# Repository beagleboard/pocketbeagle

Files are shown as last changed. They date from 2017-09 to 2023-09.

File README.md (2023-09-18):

# BeagleBoard.org PocketBeagle
_An even more bare-bones-BeagleBone made super-tiny, affordable and cloneable_

[PocketBeagle](https://beagleboard.org/pocket) is an ultra-tiny-yet-complete open-source USB-key-fob computer. PocketBeagle features an incredible low cost, slick design and simple usage, making PocketBeagle the ideal development board for beginners and professionals alike.

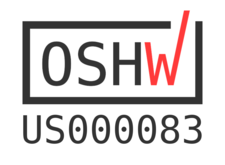
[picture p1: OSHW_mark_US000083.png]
(https://certification.oshwa.org/us000083.html)


See [documentation](https://docs.beagleboard.org/latest/boards/pocketbeagle/original/index.html) for usage details and [the forum](https://forum.beagleboard.org/tag/pocketbeagle) for support.

# Terms
These design materials are *NOT SUPPORTED* and *DO NOT* constitute a reference design. Only “community” support is allowed via resources at [BeagleBoard.org/discuss](https://beagleboard.org/discuss).

THERE IS NO WARRANTY FOR THE DESIGN MATERIALS, TO THE EXTENT PERMITTED BY APPLICABLE LAW. EXCEPT WHEN OTHERWISE STATED IN WRITING THE COPYRIGHT HOLDERS AND/OR OTHER PARTIES PROVIDE THE DESIGN MATERIALS “AS IS” WITHOUT WARRANTY OF ANY KIND, EITHER EXPRESSED OR IMPLIED, INCLUDING, BUT NOT LIMITED TO, THE IMPLIED WARRANTIES OF MERCHANTABILITY AND FITNESS FOR A PARTICULAR PURPOSE. THE ENTIRE RISK AS TO THE QUALITY AND PERFORMANCE OF THE DESIGN MATERIALS IS WITH YOU. SHOULD THE DESIGN MATERIALS PROVE DEFECTIVE, YOU ASSUME THE COST OF ALL NECESSARY SERVICING, REPAIR OR CORRECTION.

In other words, you may use the design materials as you choose and there is no license with regards to usage in the manufacturing process. We mean it, these design materials may be totally unsuitable for any purposes. Don't blame us!

As a general rule, we don't encourage use of this or other off-the-shelf single board computers in commercial products without engaging with a manufacturer to create a supplier agreement and make sure that you can get material as your business demands. Further, we do update the design on occasions where we find it necessary and won't guarantee a supply of older revisions, though we do seek periodic manufacturing of all of our boards for a period of roughly 10 years and will make design changes to replace obsolete parts and that may impact your usage. If you do opt to use it in a product, you take full responsibility for that product.

Do not use the BeagleBoard.org logo or trademarks (such as BeagleBoard, BeagleBone and PocketBeagle) on your products without a [logo license](https://beagleboard.org/logo) from the BeagleBoard.org Foundation, but feel free to reference BeagleBoard.org.

See the [LICENSE](https://github.com/beagleboard/pocketbeagle/blob/master/LICENSE) file regarding the copyright of these materials.

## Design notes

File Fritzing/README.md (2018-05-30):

# Fritzing model of PocketBeagle

[Fritzing](http://fritzing.org/) is an easy way to document your projects and even design PCBs.

This is now [upstream](https://github.com/fritzing/fritzing-parts/blob/master/core/PocketBeagle.fzp), so use the upstream version.

PocketBeagle breadboard view Breadboard style view in Fritzing

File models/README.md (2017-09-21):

This model is courtesy of Steve Smitka.

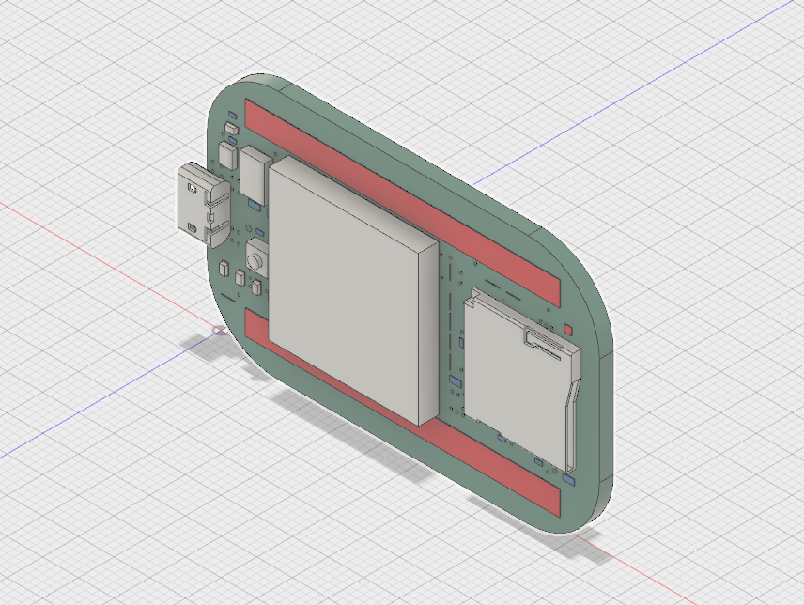
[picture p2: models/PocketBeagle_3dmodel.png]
PocketBeagle 3D model Render of 3D model


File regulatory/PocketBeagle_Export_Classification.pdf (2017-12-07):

### Commodity Classification Case Number: Z1543565 Date of Completion: December 6, 2017

UNITED STATES DEPARTMENT OF COMMERCE BUREAU OF INDUSTRY AND SECURITY WASHINGTON, D.C. 20230

FORM BXA-6002L(REV. 7/96) | Page 1 of 1

GHI Electronics
ATTN: gary beaver | G173833
501 E. Whitcomb Avenue
Madison Heights, MI 48071

THE FOLLOWING INFORMATION IS IN RESPONSE TO YOUR INQUIRY OF August 25, 2017 REQUESTING COMMODITY CLASSIFICATION(S) FOR:

COMMODITY | ECCN | SUBPARAGRAPH
PocketBeagle is an ultra-tiny-yet-complete Linux-enabled, community-supported, open-source USB-key-fob computer.
PocketBeagle
| EAR99

COMMENTS FROM LICENSING OFFICER(S):

FOR INFORMATION CONCERNING THIS CLASSIFICATION CONTACT MICHAEL PENDER
AARON AMUNDSON | PHONE #: 202-482-2458
DIVISION DIRECTOR | BIS/EA/STC/IT

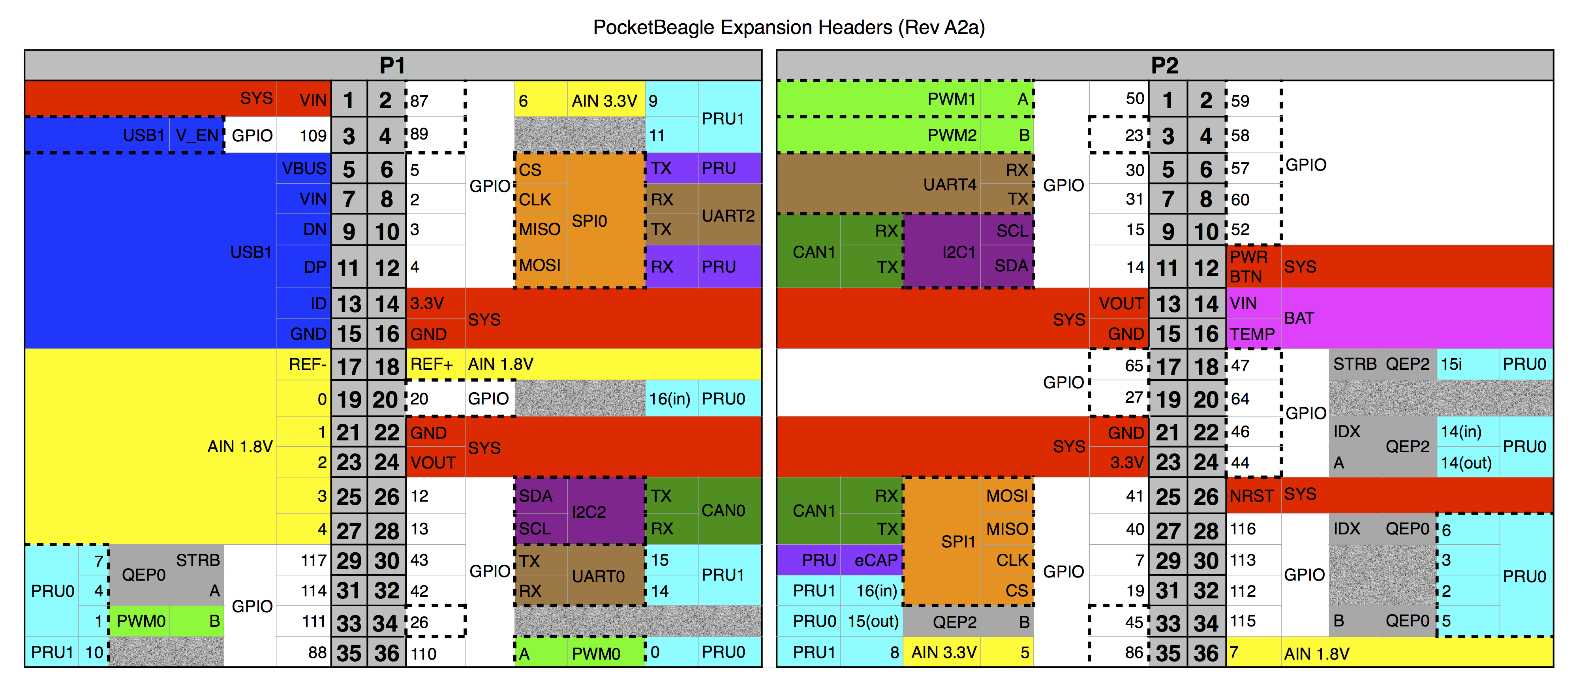
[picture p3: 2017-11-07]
docs/PocketBeagle_pinout.png

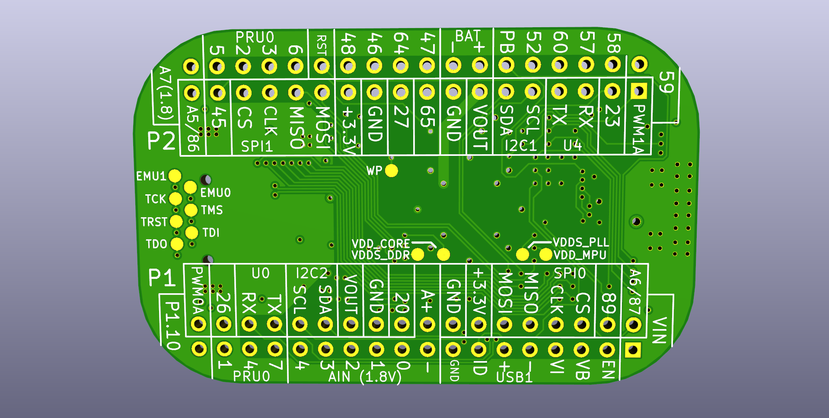
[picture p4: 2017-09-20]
KiCAD/plots/PocketBeagle-back.png

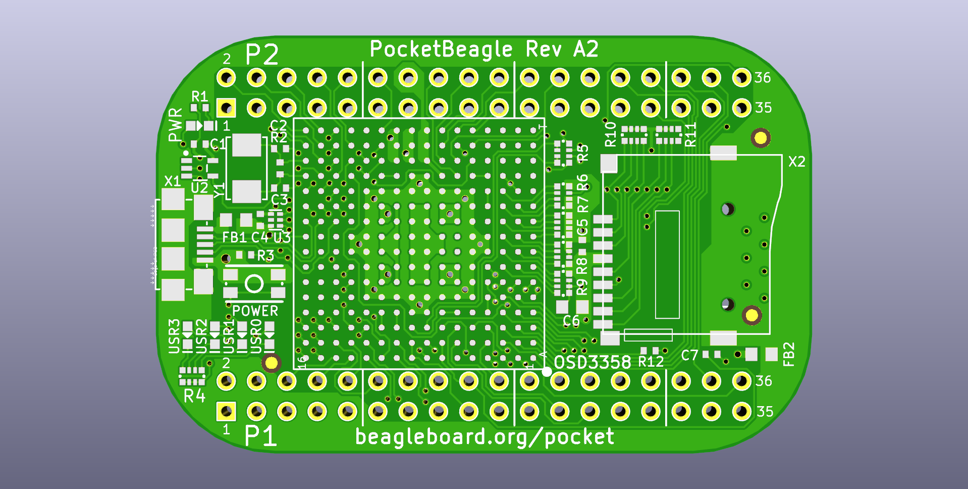
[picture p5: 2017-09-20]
KiCAD/plots/PocketBeagle-front.png

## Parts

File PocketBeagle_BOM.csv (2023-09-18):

Designator | Manufacturer/MPN | Qty | Description
 | PLACON GB1430A | 1 | 1-3/16 X1-7/8 X 1/2IN GRAPHIC BOX 770/CS
C1,C5,C7 | YAGEO CC0402KRX7R7BB104 | 3 | Cap,100nF,10%,16V,X7R,0402,YAGEO
C2,C3 | YAGEO CC0402JRNPO9BN180 | 2 | CAP 18pF 5% 50V COG 0402 SMD
C4 | YAGEO CC0402KRX5R5BB105 | 1 | CAP,1UF,+/-10%,X5R,6.3V,SMD0402
C6 | MURATA GRM21BR71A106KE51L | 1 | CAP CER 10UF 10V 10% X7R 0805 TR
D1,D2,D3,D4 | SEMITEL ESDPSA0402V05 | 4 | SMD Diode ESD 0.05pF;0402
FB1,FB2 | Laird LI0603G121R-10 | 2 | FERRITE BEAD 120 OHM 0603 1LN
POWER | C&K Components KMR231GLFS | 1 | SWITCH TACTILE SPST-NO 0.05A 32V
R1 | YAGEO RC0402FR-071KL | 1 | RES,1K,+/-1%,1/16W,SMD0402
R2 | YAGEO RC0402FR-071ML | 1 | RES,1M,+/-1%,1/16W,SMD0402
R3,R12 | YAGEO RC0402FR-0710KL | 2 | RES,10K,+/-1%,1/16W,SMD0402
R4 | YAGEO YC124-JR-071KL | 1 | RES 4 Arrays,1K,+/-5%,1/16W,SMD0804(0402X4)
R5,R10,R11 | YAGEO YC124-JR-0710KL | 3 | RES 4 Arrays,10K,+/-5%,1/16W,SMD0804(4x0402)
R6,R7,R8,R9 | YAGEO YC124-JR-07100KL | 4 | RES 4 Arrays,100K,+/-5%,1/16W,SMD0804(0402X4)
U1 | Octavo Systems OSD3358-512M-BSM | 1 | IC,the smallest System-In-Package (SiP) device in the OSD335x Family,OSD3358-512M-BSM,BGA256,SMD
U2 | Texas Instruments SN74LVC1G07DCKR | 1 | IC,SINGLE BUFFER/DRIVER WITH OPEN-DRAIN OUTPUT,SN74LVC1G07DCKR,SC-70,SMD
 | Nexperia 74LVC1G07GV,125 | 1 | IC,SINGLE BUFFER/DRIVER WITH OPEN-DRAIN OUTPUT,SN74LVC1G07DCKR,SC-70,SMD
USR0,USR1,USR2,USR3,PWR | EVERLIGHT 19-217/BHC-AN1P2/3T | 5 | LED,Blue,Water Clear,If25mA,SMD0603,464.5~476.5nm,Vf2.7~3.7v,-40~85,
X1 | MTCONN UBAF-06082, FCI 10118192-0001LF | 1 | Conn,Micro USB B,5pin,RA, SMT
X2 | MTCONN MCTF-0403, Suntech ST-TF-003A | 1 | Connector,MicroSD Card CONN with detect switch,Gold Flash 1u,Black,SMD
Y1 | Interquip 5XBB24000183TF50Q3, CTS 445A35A24M00000, TXC 7A-24.000MAAJ-T | 1 | 24MHz crystal, SMD, 5x3.2mm

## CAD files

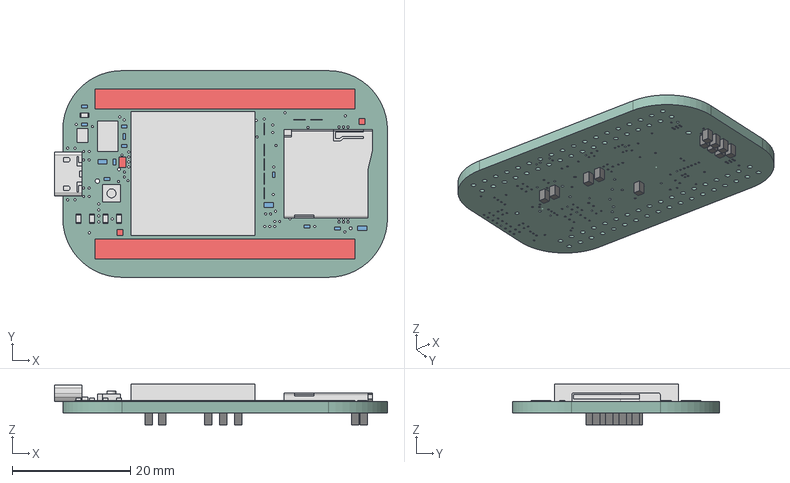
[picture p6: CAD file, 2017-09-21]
models/PocketBeagle.step
56.4 x 35.0 x 6.93 mm
Board
FIDUCIAL_40MIL x 3
0603-LED x 5
SON-6(TI)-DRY
CRYSTAL_5X3.2MM
SC70(TI-DCK)
RN0804 x 8
OSD335X-BGA-256
TH-2X18-(35MIL-DIA)-W_O-SILK x 2
B1,27 x 12
chip
sdholder
microusb port
button
leds
y1chip
powerLED
c1chip

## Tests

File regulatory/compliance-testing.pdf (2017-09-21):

Registration #
6844A-3 | Testing Laboratory

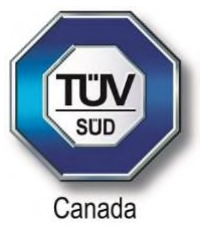
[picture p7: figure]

| Certificate #2955.02 | R-4023, G-506
| | C-4498, T-1246 Registration #
| | CA6844
Page 1 of 50 | Report Issued: 9/11/2017 | Report File #: 7169003158E-000

© TÜV SÜD Canada Inc. This test report shall not be reproduced except in full, without written approval of TÜV SÜD Canada Inc CISPR32-24_FCC_ICES_Rev2

## EMC / EMI Test Report

As per
CISPR 32:2015/EN 55032:2015, CISPR 24:2010/EN 55024:2010, AS/NZS CISPR 32:2013,

## FCC Part 15 Subpart B:2016 & ICES-003:2016

Emissions & Immunity for

Multimedia Class B Equipment on the

## Pocket Beagle A2

Issued by: | TÜV SÜD Canada Inc. 11 Gordon Collins Dr, Gormley, ON, L0H 1G0 Canada Ph: (905) 883-7255

Testing produced for

See Appendix A for full client & EUT details.
Name,
Project Engineer

Client | BeagleBoard.org Foundation
Product | PocketBeagle A2
Standard(s) | FCC Part 15 Subpart B / ICES-003 CISPR 32/EN55032 & CISPR 24/EN55024
Page 2 of 50 | Report Issued: 9/11/2017 | Report File #: 7169003158E-000

## Table of Contents

Product | PocketBeagle A2
Standard(s) | FCC Part 15 Subpart B / ICES-003 CISPR 32/EN55032 & CISPR 24/EN55024
Page 3 of 50 | Report Issued: 9/11/2017 | Report File #: 7169003158E-000

## Report Scope

This report addresses the EMC verification testing and test results of the BeagleBone, Pocket Beagle, Model: A2, herein referred to as EUT (Equipment Under Test). The EUT was tested for emissions and immunity compliance against the following standards:

EN 55032:2012/CISPR 32:2012

EN 55024:2010/CISPR 24:2010

AS/NZS CISPR 32:2013

FCC Part 15 Subpart B:2016

ICES-003:2016

Power line conducted emissions, radiated emissions, harmonics emissions, flicker emissions, and immunity testing was evaluated on the EUT. Test procedures, results, justifications, and engineering considerations, if any, follow later in this report.

For a more detailed list of the standards and the revision used, see the "Applicable Standards, Specifications and Methods" section of this report.

This report does not imply product endorsement by any government, accreditation agency, or TÜV SÜD Canada Inc.

Opinions or interpretations expressed in this report, if any, are outside the scope of TÜV SÜD Canada Inc. accreditations. Any opinions expressed do not necessarily reflect the opinions of TÜV SÜD Canada Inc., unless otherwise stated.

Product | PocketBeagle A2
Standard(s) | FCC Part 15 Subpart B / ICES-003 CISPR 32/EN55032 & CISPR 24/EN55024
Page 4 of 50 | Report Issued: 9/11/2017 | Report File #: 7169003158E-000

## Summary

The results contained in this report relate only to the item(s) tested.

Equipment Under Test (EUT) | Pocket Beagle
EUT passed all tests performed | Yes
Testing conducted by | Marty McLear

For testing dates, see 'Testing Environmental Conditions and Dates'.

Product | PocketBeagle A2
Standard(s) | FCC Part 15 Subpart B / ICES-003 CISPR 32/EN55032 & CISPR 24/EN55024
Page 5 of 50 | Report Issued: 9/11/2017 | Report File #: 7169003158E-000

Test Results Summary

Standard/ Method | Description | Criteria | Class / Level | Result
EN 55032/ CISPR 32 FCC 15 - ICES 003 | Radiated Emissions | N/A | Class B | Pass
EN 55024/ EN 61000-4-2 | Electro-Static Discharge | B | ±4kV Contact ±8kV Air | Pass
EN 55024/ EN 61000-4-3 | Radiated Field Immunity | A | 3 V/m, 80 MHz – 1 GHz | Pass
EN 55024/ EN 61000-4-4 | Electrical Fast Transients (Bursts) | B | ±0.5kV - I/O | Pass
EN 55024/ EN 61000-4-8 | Power Frequency Magnetic Field | A | 1 A/m (3 A/m Tested) | Pass
Overall Result | | | | Pass

If the product as tested complies with the specification or requirement, the EUT is deemed to comply and is issued a 'PASS' grade. If not, 'FAIL' grade is issued.

Product | PocketBeagle A2
Standard(s) | FCC Part 15 Subpart B / ICES-003 CISPR 32/EN55032 & CISPR 24/EN55024
Page 6 of 50 | Report Issued: 9/11/2017 | Report File #: 7169003158E-000

Notes, Justifications, or Deviations
The following justifications for tests not performed or deviations from the above listed specifications apply:

Client has stated that this equipment is consider a DC device and that the EUT is not intended to be used with a AC/DC power adaptor as part of their system.
The following tests are therefore not applicable for a DC powered device:
- Conducted Emissions
- Power Line Harmonics Emissions
- Flicker Emissions
- Surge Immunity
- Conducted RF Immunity
- Voltage Dips and Interrupts

The client has indicated that the EUT / PCB will be ESD Sensitive and is marked with the ESD Sensitive marking on the silk screen of the PCB.

A later revision of the standard may have been substituted in place of the previous dated referenced revision. The year of the specification used is listed under applicable standards. Using the later revision accomplishes the goal of ensuring compliance to the intent of the previous specification, while allowing the laboratory to incorporate the extensions and clarifications made available by a later revision.

Sample Calculation(s)
Radiated Emission Test
Margin = Limit – (Received Signal + Antenna Factor + Cable Loss – Pre-Amp Gain) Margin = 50dBµV/m – (50dBµV + 10dB + 2.5dB – 20dB)
Margin = 7.5 dB (pass)

Power Line Conducted Emission Test
Margin = Limit – (Received Signal + Attenuation Factor + Cable Loss + LISN Factor) Margin = 73.0dBµV – (50dBµV + 10dB + 2.5dB + 0.5dB)
Margin = 10.0 dB (pass)

Milligauss to A/m Conversion (Magnetic Immunity)
1A/m = 12.57 mG
3A/m = 3*12.57 = 37.7 mG

Product | PocketBeagle A2
Standard(s) | FCC Part 15 Subpart B / ICES-003 CISPR 32/EN55032 & CISPR 24/EN55024
Page 7 of 50 | Report Issued: 9/11/2017 | Report File #: 7169003158E-000

## Applicable Standards, Specifications and Methods

ANSI C63.4:2014 Methods of Measurement of Radio-Noise Emissions from Low-Voltage Electrical and Electronic Equipment in the Range of 9 kHz to 40 GHz CFR47 FCC Part 15
Subpart B:2016

Code of Federal Regulations - Radio Frequency Devices

ICES-003, Issue 6
2016

Information Technology Equipment (ITE) - Limits and Methods of Measurement
EN55032:2012/
CISPR32:2012

Electromagnetic Compatibility of Multimedia Equipment – Emission Requirements
EN55024:2010/
CISPR24:2010

Information Technology Equipment - Immunity Characteristics -Limits and Methods of Measurement
AS/NZS CISPR32:2013 Electromagnetic Compatibility of Multimedia Equipment – Emission Requirements
CISPR 16-2-3:2010/A2:2014 Specification for Radio Disturbance and Immunity Measuring Apparatus and Methods - Part 2-3: Methods of Measurement of Disturbances and Immunity - Radiated Disturbance Measurements
IEC/EN 61000-3-2:2014 Limits for Harmonic Current Emissions
(equipment input current ≤ 16A per phase)
IEC/EN 61000-3-3:2013 Limitation of Voltage Changes, Voltage Fluctuations and Flicker in Public Low-Voltage Supply Systems, for equipment with rated current ≤ 16A per phase and not subject to conditional connection. IEC 61000-4-2:2008
EN 61000-4-2:2009

Testing and Measurement Techniques -
Electrostatic Discharge Immunity Test IEC/EN 61000-4-3:2006/
A2:2010

Testing and Measurement Techniques -
Radiated, Radio-Frequency, Electromagnetic Field Immunity Test IEC/EN 61000-4-4:2004 Testing and Measurement Techniques -Electrical Fast Transient/Burst Immunity Test
IEC 61000-4-5:2005
EN 61000-4-5:2006

Testing and Measurement Techniques - Surge Immunity Test

IEC 61000-4-6:2008
EN 61000-4-6:2009

Testing and Measurement Techniques - Immunity to Conducted Disturbances, Induced by Radio-Frequency Fields
IEC 61000-4-8:2009
EN 61000-4-8:2010

Testing and Measurement Techniques -
Power Frequency Magnetic Field Immunity Test IEC/EN 61000-4-11:2004 Testing and Measurement Techniques - Voltage Dips, Short Interruptions and Voltage Variations Immunity Tests
ISO 17025:2005 General Requirements for the Competence of Testing and Calibration Laboratories

Product | PocketBeagle A2
Standard(s) | FCC Part 15 Subpart B / ICES-003 CISPR 32/EN55032 & CISPR 24/EN55024
Page 8 of 50 | Report Issued: 9/11/2017 | Report File #: 7169003158E-000

## Document Revision Status

Revision 0 September 8th, 2017 Initial Release

Product | PocketBeagle A2
Standard(s) | FCC Part 15 Subpart B / ICES-003 CISPR 32/EN55032 & CISPR 24/EN55024
Page 9 of 50 | Report Issued: 9/11/2017 | Report File #: 7169003158E-000

## Definitions and Acronyms

The following definitions and acronyms are applicable in this report. See also ANSI C63.14.

AM – Amplitude Modulation
CDN – Coupling Decoupling Network
EFT – Electrical Fast Transients
ESD – Electro-Static Discharge
HCP – Horizontal Coupling Plane
VCP – Vertical Coupling Plane
LISN – Line Impedance Stabilization Network NCR – No Calibration Required
NSA – Normalized Site Attenuation
N/A – Not Applicable
RF – Radio Frequency

AE – Associated Equipment. Equipment needed to exercise and/or monitor the operation of the EUT.

Class A Device – A device that is marketed for use in a commercial, industrial or business environment. A 'Class A' device should not be marketed for use by the general public. A 'Class A' device should contain a warning notice in the user manual stating that it could cause radio interference. For example: "Warning: Operation of this equipment in a residential environment could cause radio interference."

Class B Device – A device that is marketed for use in a residential environment and may also be used in a commercial, business or industrial environments. NOTE: A residential environment is an environment where the use of broadcast radio and television receivers may be expected within a distance of 10m of the device concerned.

EMC – Electro-Magnetic Compatibility. The ability of an equipment or system to function satisfactorily in its electromagnetic environment without introducing intolerable electromagnetic disturbances to anything in that environment.

EMI – Electro-Magnetic Immunity. The ability to maintain a specified performance when the equipment is subjected to disturbance (unwanted) signals of specified levels.

EUT – Equipment Under Test. A device or system being evaluated for compliance that is representative of a product to be marketed.

Product | PocketBeagle A2
Standard(s) | FCC Part 15 Subpart B / ICES-003 CISPR 32/EN55032 & CISPR 24/EN55024
Page 10 of 50 | Report Issued: 9/11/2017 | Report File #: 7169003158E-000

ITE – Information Technology Equipment. Has a primary function of entry, storage, display, retrieval, transmission, processing, switching, or control of data and/or telecommunication messages and which may be equipped with one or more ports typically for information transfer.

Antenna Port – Port, other than a broadcast receiver tuner port, for connection of an antenna used for intentional transmission and/or reception of radiated RF energy.

Broadcast Receiver Tuner Port – Port intended for the reception of a modulated RF signal carrying terrestrial, satellite and/or cable transmissions of audio and/or video broadcast and similar services.

Optical Fiber Port – Port at which an optical fiber is connected to an equipment.

Signal/Control Port – Port intended for the interconnection of components of a EUT, or between a EUT and local AE and used in accordance with relevant functional specifications (for example for the maximum length of cable connected to it).
(Examples include: RS-232, USB, HDMI, Fire Wire)

Wired Network Port – Point of connection for voice, data and signaling transfers intended to interconnect widely dispersed systems by direct connection to a single-user or multi-user communication network.
(Examples include: CATV, PSTN, ISDN, xDSL, LAN and similar networks)

EMC Test Plan – An EMC test plan established prior to testing. See 'Appendix A – EUT & Client Provided Details'.

Product | PocketBeagle A2
Standard(s) | FCC Part 15 Subpart B / ICES-003 CISPR 32/EN55032 & CISPR 24/EN55024
Page 11 of 50 | Report Issued: 9/11/2017 | Report File #: 7169003158E-000

## Testing Facility

Testing for EMC on the EUT was carried out at TÜV SÜD Canada testing lab near Toronto, Ontario. The testing lab has a calibrated 3m semi-anechoic chamber which allows measurements on a EUT that has a maximum width or length of up to 2m and a height of up to 3m. The chamber is equipped with a turntable that is capable of testing devices up to 3300lb in weight. This facility is capable of testing products that are rated for 120Vac and 240Vac single phase, or devices that are rated for a 208Vac 3 phase input. DC capability is also available for testing. The chamber is equipped with a mast that controls the polarization and height of the antenna. Control of the mast occurs in the control room adjoining the shielded chamber. Radiated emission measurements are performed using a BiLog antenna and a Horn antenna where applicable. Conducted emissions, unless otherwise stated, are performed using a LISN and using the Vertical Ground plane if applicable.

Calibrations and Accreditations
The 3m semi-anechoic chamber is registered with Federal Communications Commission (FCC, CA6844), Industry Canada (IC, 6844A-3) and Voluntary Control Council for Interference (VCCI, R-4023, G-506, C-4498, and T-1246). This chamber was calibrated for Normalized Site Attenuation (NSA) using test procedures outlined in ANSI C63.4 "Methods of Measurement of Radio-Noise Emissions from Low-Voltage Electrical and Electronic Equipment in the Range of 9 kHz to 40 GHz". The chamber is lined with ferrite tiles and absorption cones to minimize any undesired reflections. The NSA data is kept on file at TÜV SÜD Canada. For radiated susceptibility testing, a 16 point field calibration has been performed on the chamber. The field uniformity data is kept on file at TÜV SÜD Canada. TÜV SÜD Canada Inc. is accredited to ISO 17025 by A2LA with Testing Certificate #2955.02. The laboratory's current scope of accreditation listing can be found as listed on the A2LA website. All measuring equipment is calibrated on an annual or bi-annual basis as listed for each respective test.

Product | PocketBeagle A2
Standard(s) | FCC Part 15 Subpart B / ICES-003 CISPR 32/EN55032 & CISPR 24/EN55024
Page 12 of 50 | Report Issued: 9/11/2017 | Report File #: 7169003158E-000

Testing Environmental Conditions and Dates
Following environmental conditions were recorded in the facility during time of testing:
Date | Test | Initials | Temperature (ºC) | Humidity (%) | Pressure (kPa)
September 6th, 2017 | Radiated Emissions | MM | 23.5 | 49.3 | 100.5
September 6th, 2017 | Electro-Static Discharge | MM | 23.5 | 49.3 | 100.5
September 6th, 2017 | Radiated Field Immunity | MM | 23.5 | 49.3 | 100.5
September 5th, 2017 | Electrical Fast Transients | MM | 22.1 | 56.1 | 99.9
September 6th, 2017 | Power Frequency Magnetic Field | MM | 23.5 | 49.3 | 100.5

Product | PocketBeagle A2
Standard(s) | FCC Part 15 Subpart B / ICES-003 CISPR 32/EN55032 & CISPR 24/EN55024
Page 13 of 50 | Report Issued: 9/11/2017 | Report File #: 7169003158E-000

## Detailed Test Result Section

Product | PocketBeagle A2
Standard(s) | FCC Part 15 Subpart B / ICES-003 CISPR 32/EN55032 & CISPR 24/EN55024
Page 14 of 50 | Report Issued: 9/11/2017 | Report File #: 7169003158E-000

Radiated Emissions

Purpose
The purpose of this test is to ensure that the RF energy unintentionally emitted from the EUT does not exceed the limits listed below as defined in the applicable test standard and measured from a receiving antenna. This helps protect broadcast radio services such as television, FM radio, pagers, cellular telephones, emergency services, and so on, from unwanted interference.

Limits & Method
The limits and method are as defined in ANSI C63.4 and CISPR 32, EN55032, 47 CFR FCC Part 15 Section 15.109(g), and ICES-003 Issue 6 Section 6.2:
CLASS A
Frequency Rangea | Quasi-Peak Limits - 10mb | Quasi-Peak Limits - 3mb
30 MHz – 230 MHz | 40 dBµV/m | 50 dBµV/m
230 MHz – 1 GHz | 47 dBµV/m | 57 dBµV/m

CISPR 32 / EN 55032,
Frequency Rangea | Average Limit - 3mc | Peak Limit - 3md
1 GHz – 3 GHz | 56 dBµV/m | 76 dBµV/m
3 GHz – 6 GHz | 60 dBµV/m | 80 dBµV/m

FCC Part 15 Subpart B,
Frequency Rangea | Average Limit - 3mc | Peak Limit - 3md
1 GHz and Up | 60 dBµV/m | 80 dBµV/m

aThe frequency range scanned is in accordance to CISPR 32 Table 1 and FCC Part 15 Section 15.33(b).
bLimit is with a resolution bandwidth of 120 kHz, a video bandwidth at least three times greater than the resolution bandwidth, and using a Quasi-Peak detector.
cLimit is with a resolution bandwidth of 1 MHz and using an Average detector.
dLimit is with a resolution bandwidth of 1 MHz, a video bandwidth at least three times greater than the resolution bandwidth, and using a Peak detector.

Based on ANSI C63.4 Section 4.2 and CISPR 32 Annex C.3, if the Peak detector measurements do not exceed the Quasi-Peak limits, where defined, then the EUT is deemed to have passed the requirements.

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

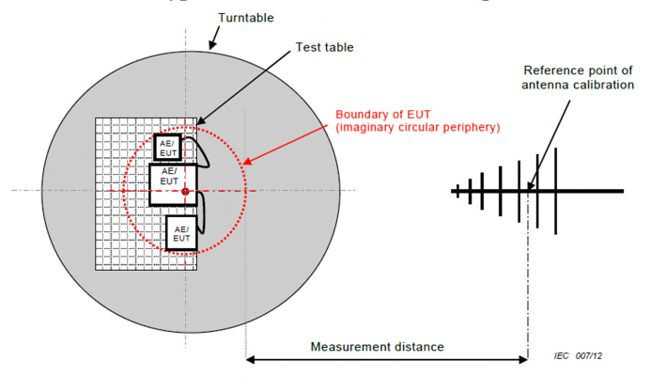
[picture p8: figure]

Page 15 of 50 | Report Issued: 9/11/2017 | Report File #: 7169003158E-000

Typical Radiated Emissions Setup

Note: In accordance with CISPR 32 Annex C, testing was performed at a 3 meter test distance.

Measurement Uncertainty
The expanded measurement uncertainty is calculated in accordance with CISPR 16-4-2 and is ±4.25dB for 30MHz – 1GHz and ±4.93dB for 1GHz – 18GHz with a 'k=2' coverage factor and a 95% confidence level.

Preliminary Graphs
The graphs shown below are maximized peak measurement graphs measured with a resolution bandwidth greater than or equal to the final required detector over a full 0-360°. This peaking process is done as a worst case measurement and enables the detection of frequencies of concern for final measurement. For final measurements with the appropriate detector, where applicable, please refer to the tables under Final Measurements.

In accordance with FCC Part 15, Subpart A, Section 15.33 and CISPR 32 Table 1, the EUT was scanned to a minimum of a 1 GHz. For devices containing clocks higher than 108 MHz, they were scanned above 1 GHz to meet the requirements of FCC Part 15 Section 15.33 and CISPR 32.

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

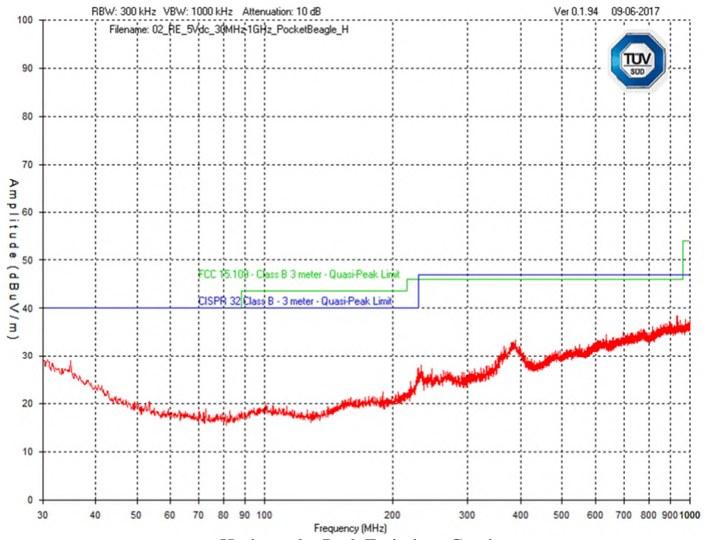
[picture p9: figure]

Page 16 of 50 | Report Issued: 9/11/2017 | Report File #: 7169003158E-000

Horizontal – Peak Emissions Graph 5Vdc – 30MHz - 1GHz

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

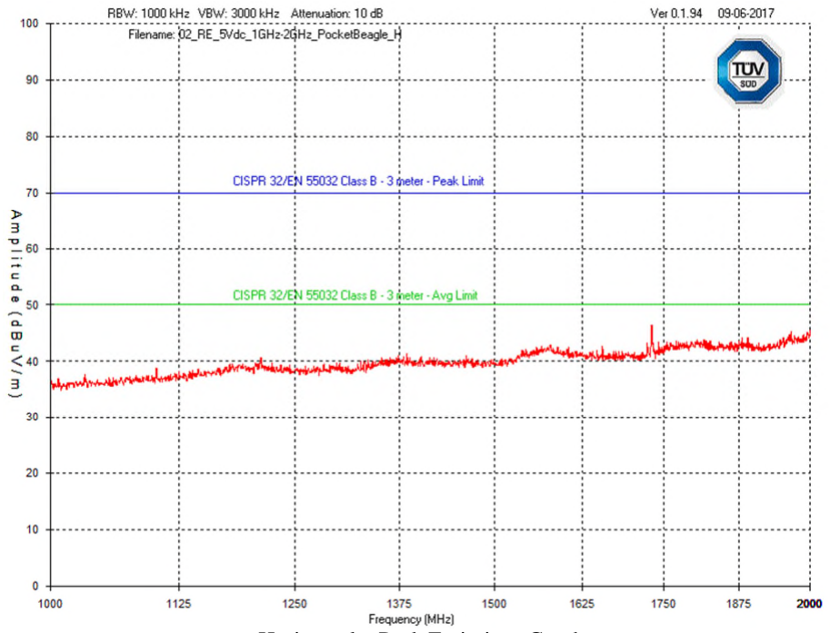
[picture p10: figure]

Page 17 of 50 | Report Issued: 9/11/2017 | Report File #: 7169003158E-000

Horizontal – Peak Emissions Graph 5Vdc – 1GHz - 2GHz (CISPR 32/EN 55032)

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

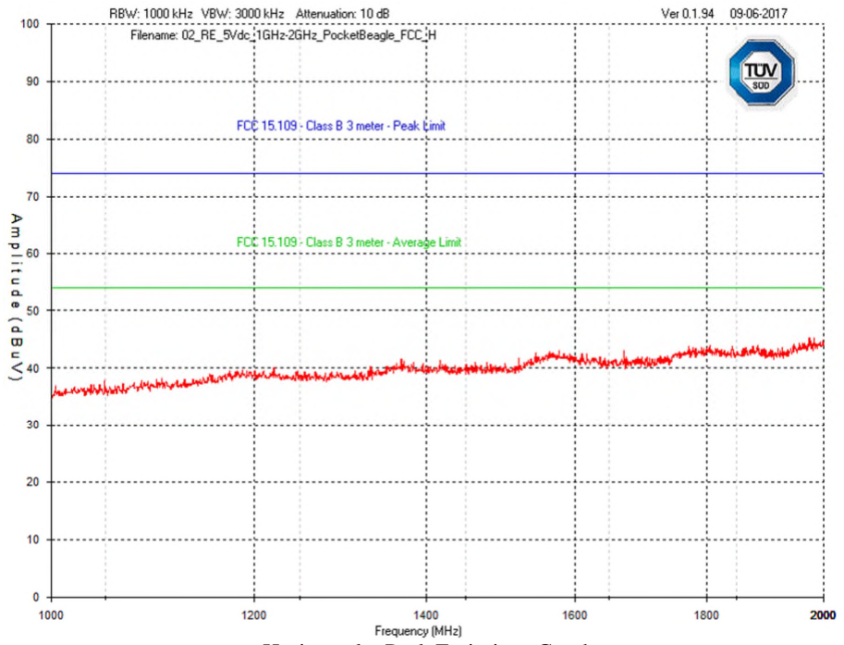
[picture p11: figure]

Page 18 of 50 | Report Issued: 9/11/2017 | Report File #: 7169003158E-000

Horizontal – Peak Emissions Graph 5Vdc – 1GHz - 2GHz (FCC 15.109)

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

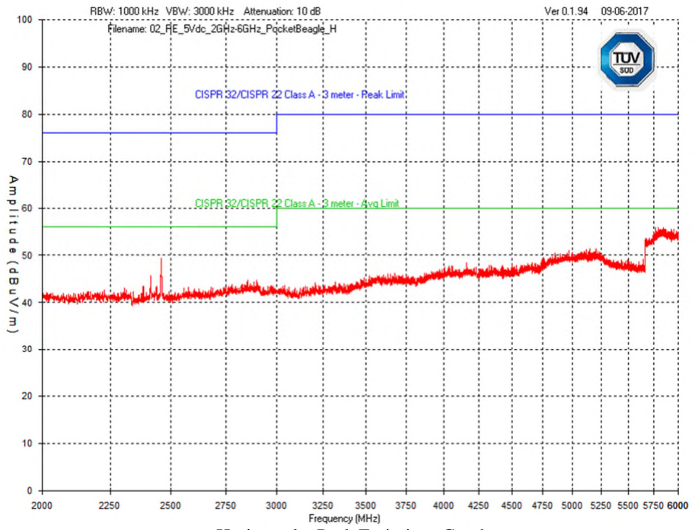
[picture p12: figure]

Page 19 of 50 | Report Issued: 9/11/2017 | Report File #: 7169003158E-000

Horizontal – Peak Emissions Graph 5Vdc – 2GHz - 6GHz (CISPR 32/EN 55032)

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

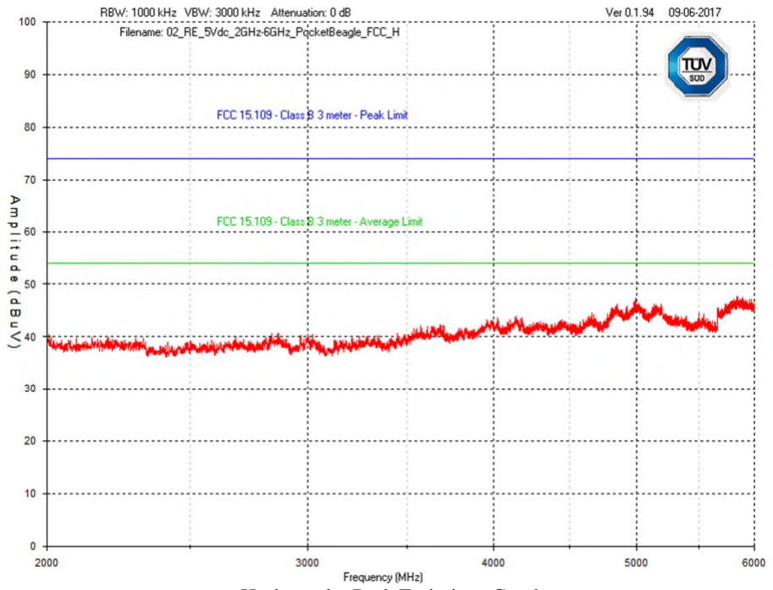
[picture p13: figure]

Page 20 of 50 | Report Issued: 9/11/2017 | Report File #: 7169003158E-000

Horizontal – Peak Emissions Graph 5Vdc – 2GHz - 6GHz (FCC 15.109)

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

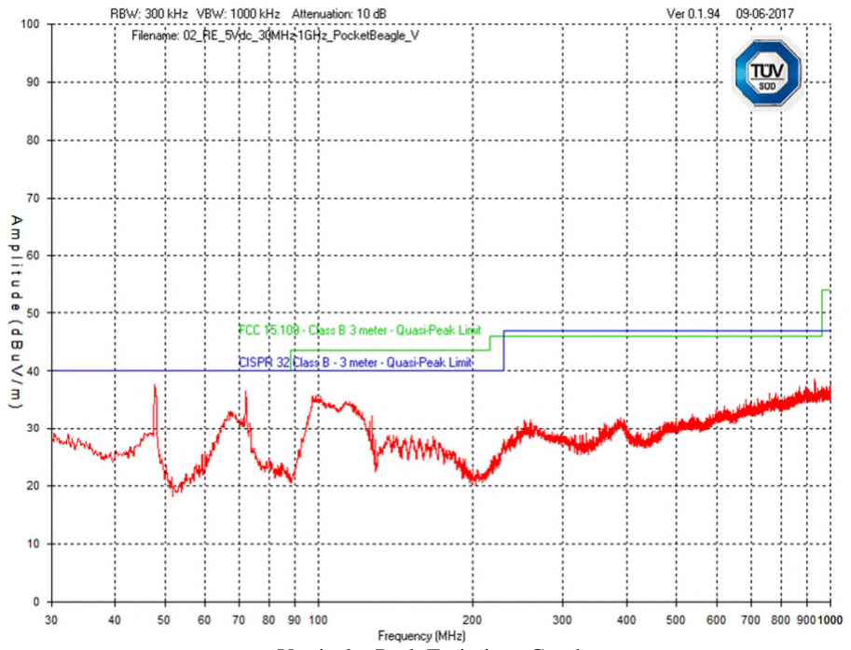
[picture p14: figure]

Page 21 of 50 | Report Issued: 9/11/2017 | Report File #: 7169003158E-000

Vertical – Peak Emissions Graph 5Vdc – 30MHz - 1GHz

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

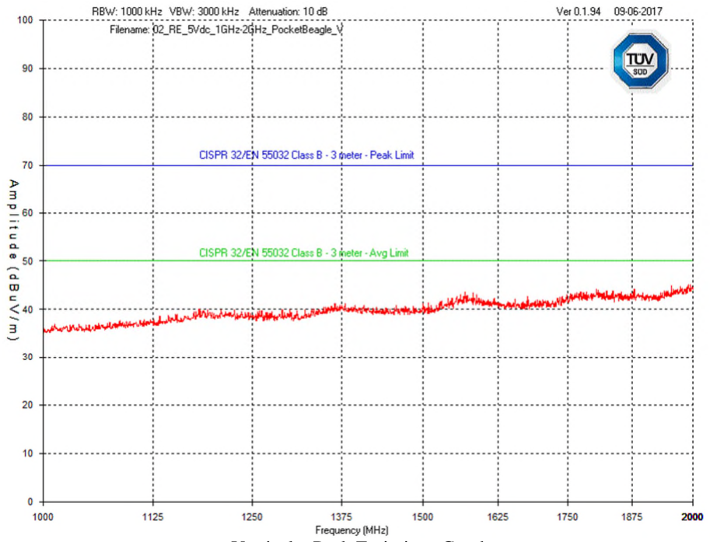
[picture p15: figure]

Page 22 of 50 | Report Issued: 9/11/2017 | Report File #: 7169003158E-000

Vertical – Peak Emissions Graph 5Vdc – 1GHz - 2GHz (CISPR 32/EN 55032)

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

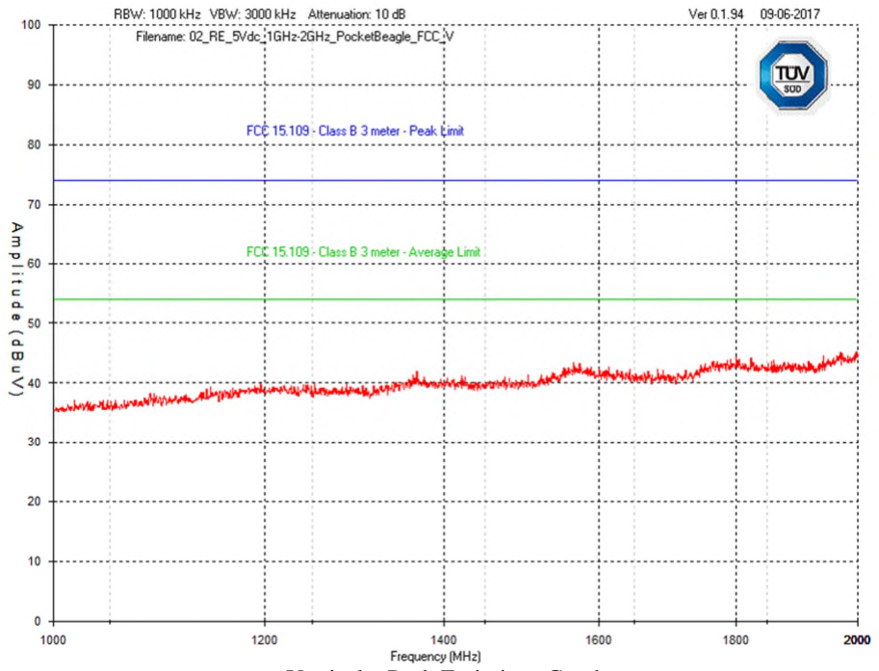
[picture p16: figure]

Page 23 of 50 | Report Issued: 9/11/2017 | Report File #: 7169003158E-000

Vertical – Peak Emissions Graph 5Vdc – 1GHz - 2GHz (FCC 15.109)

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


Page 24 of 50 | Report Issued: 9/11/2017 | Report File #: 7169003158E-000

Vertical – Peak Emissions Graph 5Vdc – 2GHz - 6GHz (CISPR 32/EN 55032)

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


Page 25 of 50 | Report Issued: 9/11/2017 | Report File #: 7169003158E-000

Vertical – Peak Emissions Graph 5Vdc – 2GHz - 6GHz (FCC 15.109)

Product | PocketBeagle A2
Standard(s) | FCC Part 15 Subpart B / ICES-003 CISPR 32/EN55032 & CISPR 24/EN55024
Page 26 of 50 | Report Issued: 9/11/2017 | Report File #: 7169003158E-000

Final Measurements
The worst case measurement as listed in the table below appeared at a vertical antenna height of 100 cm and a table azimuth of 360 degrees, as pictured in Appendix B.
Product Category | Class B - CISPR 32/ EN 55032
Supply | 5Vdc
Frequency (MHz) | Detector Peak/QP | Received Signal (dBµV) | Antenna Factor (dB/m) | Atten Factor (dB) | Cable Factor (dB) | Pre-Amp (dB) | Level (dBµV/m) | QP Limit (dBµV/m) | QP Margin (dB) | Pass/ Fail

Horizontal Antenna Polarization
45.43 | QP | 28.5 | 9.0 | 6 | 0.4 | -31.7 | 12.2 | 40.0 | 27.8 | Pass
712.00 | QP | 39.8 | 6.4 | 6 | 0.5 | -32.5 | 20.2 | 40.0 | 19.8 | Pass
47.85 | PEAK | 54.0 | 9.0 | 6 | 0.4 | -31.7 | 37.7 | 40.0 | 2.3 | Pass
71.90 | PEAK | 56.2 | 6.4 | 6 | 0.5 | -32.5 | 36.6 | 40.0 | 3.4 | Pass
98.87 | PEAK | 54.3 | 8.0 | 6 | 0.6 | -33.0 | 35.9 | 40.0 | 4.1 | Pass
992.82 | PEAK | 36.7 | 23.8 | 6 | 2.5 | -33.2 | 35.8 | 47.0 | 11.2 | Pass
Vertical Antenna Polarization
931.62 | PEAK | 39.9 | 23.4 | 6 | 2.3 | -33.2 | 38.4 | 47.0 | 8.6 | Pass
30.78 | PEAK | 36.4 | 17.3 | 6 | 0.3 | -30.9 | 29.1 | 40.0 | 10.9 | Pass
763.42 | PEAK | 37.2 | 22.3 | 6 | 2.1 | -33.4 | 34.2 | 47.0 | 12.8 | Pass
388.22 | PEAK | 43.2 | 16.5 | 6 | 1.4 | -33.6 | 33.5 | 47.0 | 13.5 | Pass
233.41 | PEAK | 42.9 | 11.7 | 6 | 1.0 | -33.6 | 28.0 | 47.0 | 19.0 | Pass
246.99 | PEAK | 41.7 | 12.2 | 6 | 1.0 | -33.6 | 27.3 | 47.0 | 19.7 | Pass

Quasi-Peak Emissions Table - CISPR 32/ EN 55032

Product | PocketBeagle A2
Standard(s) | FCC Part 15 Subpart B / ICES-003 CISPR 32/EN55032 & CISPR 24/EN55024
Page 27 of 50 | Report Issued: 9/11/2017 | Report File #: 7169003158E-000
Product Category | Class B - FCC Subpart B 15.109
Supply | 5Vdc
Frequency (MHz) | Detector Peak/QP | Received Signal (dBµV) | Antenna Factor (dB/m) | Atten Factor (dB) | Cable Factor (dB) | Pre-Amp (dB) | Level (dBµV/m) | QP Limit (dBµV/m) | QP Margin (dB) | Pass/ Fail

Horizontal Antenna Polarization
45.43 | QP | 28.5 | 9.0 | 6 | 0.4 | -31.7 | 12.2 | 40.0 | 27.8 | Pass
712.00 | QP | 39.8 | 6.4 | 6 | 0.5 | -32.5 | 20.2 | 40.0 | 19.8 | Pass
47.85 | PEAK | 54.0 | 9.0 | 6 | 0.4 | -31.7 | 37.7 | 40.0 | 2.3 | Pass
71.90 | PEAK | 56.2 | 6.4 | 6 | 0.5 | -32.5 | 36.6 | 40.0 | 3.4 | Pass
98.87 | PEAK | 54.3 | 8.0 | 6 | 0.6 | -33.0 | 35.9 | 43.5 | 7.6 | Pass
992.82 | PEAK | 36.7 | 23.8 | 6 | 2.5 | -33.2 | 35.8 | 54.0 | 18.2 | Pass
Vertical Antenna Polarization
931.62 | PEAK | 39.9 | 23.4 | 6 | 2.3 | -33.2 | 38.4 | 46.0 | 7.6 | Pass
30.78 | PEAK | 36.4 | 17.3 | 6 | 0.3 | -30.9 | 29.1 | 40.0 | 10.9 | Pass
763.42 | PEAK | 37.2 | 22.3 | 6 | 2.1 | -33.4 | 34.2 | 46.0 | 11.8 | Pass
388.22 | PEAK | 43.2 | 16.5 | 6 | 1.4 | -33.6 | 33.5 | 46.0 | 12.5 | Pass
233.41 | PEAK | 42.9 | 11.7 | 6 | 1.0 | -33.6 | 28.0 | 46.0 | 18.0 | Pass
246.99 | PEAK | 41.7 | 12.2 | 6 | 1.0 | -33.6 | 27.3 | 46.0 | 18.7 | Pass

Quasi-Peak Emissions Table – FCC Subpart B 15.109

Note:
Peak = Peak measurement
QP = Quasi-Peak measurement
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

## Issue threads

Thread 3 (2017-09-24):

Boot debugging

yuvadm, 2017-09-24:
I'm attempting to boot an existing BeagleBone image I have on an SD card (and then debug to see if there are any require changes for the new board), however I'm not getting any signs of life from the board other than a steady blue LED.

Are there any hardware pins I can use to get serial UART output from the bootloader to debug the boot sequence? Is there any official flow I can follow to get the board to boot from a well-known image?

jadonk, 2017-09-25:
Yes, the UART0 pins are active logging during SPL/u-boot and the same port will also send boot requests (triggered by on-board ROM) if other boot sources are not identified (you can even boot over USB).

To see the console output, I recommend connecting one of these: https://shop.mikroe.com/ftdi-click (available from several distributors).

yuvadm, 2017-09-25:
@jadonk thanks for the tip! Unfortunately I'm not getting anything on the UART0 pins. I'm connecting the USB connector to a 5V power supply, and I have an FTDI running `screen /dev/ttyUSB0 115200` with RX/TX pairs crossed and a shared ground on any of the GND pins. Nothing is coming up over the wire, neither when I boot from an SD card, nor when there's no SD card at all. Is there anything I'm missing?

Also, can you describe how to boot over USB? That sounds interesting!

Fuegomar, 2017-10-01:
... some tips that might help you

https://debian.beagleboard.org/images/bone-debian-9.1-iot-armhf-2017-09-21-4gb.img.xz
... working when booting from an unmodified /rootfs/boot/uEnv.txt

##enable Generic eMMC Flasher:
##make sure, these tools are installed: dosfstools rsync
#cmdline=init=/opt/scripts/tools/eMMC/init-eMMC-flasher-v3.sh

... then ssh into debian@192.168.7.2 (password=temppwd)
... or use your web browser to 192.138.7.2

However, removing the comment '#' from #cmdline=init=/opt/scripts/tools/eMMC/init-eMMC-flasher-v3.sh so as to read

##enable Generic eMMC Flasher:
##make sure, these tools are installed: dosfstools rsync
cmdline=init=/opt/scripts/tools/eMMC/init-eMMC-flasher-v3.sh

and booting from the SDcard will hang all 4 leds and the board gets hot (but does not let out the magic smoke)

// change  /rootfs/etc/ssh/sshd_config for root login as follows...
#LoginGraceTime 2m
#PermitRootLogin prohibit-password // change to PermitRootLogin yes
PermitRootLogin yes
#StrictModes yes
#MaxAuthTries 6
#MaxSessions 10

RobertCNelson, 2017-10-02:
@Fuegomar there is no eMMC on the PocketBeagle, so don't "enable" /opt/scripts/tools/eMMC/init-eMMC-flasher-v3.sh  and expect it to do something..

```
However, removing the comment '#' from #cmdline=init=/opt/scripts/tools/eMMC/init-eMMC-flasher-v3.sh so as to read

##enable Generic eMMC Flasher:
##make sure, these tools are installed: dosfstools rsync
cmdline=init=/opt/scripts/tools/eMMC/init-eMMC-flasher-v3.sh
```
Regards,

Fuegomar, 2017-10-02:
Ok and thank you!

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

wcontello, 2017-10-12:
I am not clear from these posts whether I *must* modify files to get the Pocket Beagle to boot from an SD card flashed with the image "bone-debian-9.2-iot-armhf-2017-10-10-4gb.img.xz" using the tool "Etcher" on mac OS X.

So the question is... if Etcher completed the flaming procedure onto a 32GB micro SD card and I insure the card in the Pocket Beagle, then power up from a USB port, should it boot?

When I observe is the BLU LED on solid (labeled "PWR")  the four LEDs (labeled "USR23", "USR2", "USR1", and "USR0") never google or flash AND the board gets hot (not too hot to touch, but hot)

RobertCNelson, 2017-10-12:
@wcontello did you press the power button?

wcontello, 2017-10-12:
No.  I did not press any buttons.  I will try that.

Single press, then release... nothing
Press, hold (to count of 1), release, nothing
Press, hold (to count of 2), release, nothing
Press, hold (to count of 5), release, nothing

Any other ideas?

wcontello, 2017-10-12:
If I hold the power button to a count of 10, then the BLU LED turns off.  If I press, then release, then LED turns back on.  So I guess the image is incorrect?

wcontello, 2017-10-12:
I can mount the SD card from a virtual Debian machine on macOS X.  Here is a screenshot of the root folder:
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

wcontello, 2017-10-12:
The image shasum matched.

Proton:~ wayne$ shasum -b -a 256 ~/Downloads/bone-debian-9.2-iot-armhf-2017-10-10-4gb.img.xz
be1eac7a5e526930155520215329a6c39071b82199c0745c300e68b7e6c7180b */Users/wayne/Downloads/bone-debian-9.2-iot-armhf-2017-10-10-4gb.img.xz

RobertCNelson, 2017-10-12:
Humm, that's what i'm getting, why did the script generate a different value..

```
rcnee@debian:~/web/rootfs/bb.org/testing/2017-10-10/stretch-iot$ cat debian-9.2-iot-armhf-2017-10-10.tar.xz.sha256sum
167e8d3d6a4f105c4ae254c0dfb8170caeba9a2a070b2f048b20aa6c8586f584  debian-9.2-iot-armhf-2017-10-10.tar.xz
```

linode:
```
rcnee@debian:~/web/rootfs/bb.org/testing/2017-10-10/stretch-iot$ sha256sum bone-debian-9.2-iot-armhf-2017-10-10-4gb.img.xz
be1eac7a5e526930155520215329a6c39071b82199c0745c300e68b7e6c7180b  bone-debian-9.2-iot-armhf-2017-10-10-4gb.img.xz
```

nas:
```
voodoo@nuc-git:/var/www/html/rcn-ee.us/rootfs/bb.org/testing/2017-10-10/stretch-iot$ sha256sum bone-debian-9.2-iot-armhf-2017-10-10-4gb.img.xz
be1eac7a5e526930155520215329a6c39071b82199c0745c300e68b7e6c7180b  bone-debian-9.2-iot-armhf-2017-10-10-4gb.img.xz
```

Local copy i download that day:
```
voodoo@hades:/opt/images/bb.org/testing/2017-10-10/stretch-iot$ sha256sum bone-debian-9.2-iot-armhf-2017-10-10-4gb.img.xz
be1eac7a5e526930155520215329a6c39071b82199c0745c300e68b7e6c7180b  bone-debian-9.2-iot-armhf-2017-10-10-4gb.img.xz
```

wcontello, 2017-10-12:
The has matches what's on the website: https://beagleboard.org/latest-images
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

wcontello, 2017-10-13:
Should I expect the image "bone-debian-9.2-iot-armhf-2017-10-10-4gb.img.xz" to boot a Pocket Beagle when flashed to an SD card using Etcher?

And what should I expect when connected to a host system running macOS X?

Morantz, 2017-10-13:
I have had no issues booting my PocketBeagle with this image.  I used Etcher on a Win10 Laptop to write image to a class 4 MicroSD card. -  Dan Brown 
"My doctor says that I have a malformed public-duty gland and a natural deficiency in moral fibre, and that I am therefore excused from saving Universes." ~Douglas Adams

      From: wcontello <notifications@github.com>
 To: beagleboard/pocketbeagle <pocketbeagle@noreply.github.com>
Cc: Subscribed <subscribed@noreply.github.com>
 Sent: Friday, October 13, 2017 8:50 AM
 Subject: Re: [beagleboard/pocketbeagle] Boot debugging (#3)

Should I expect the image "bone-debian-9.2-iot-armhf-2017-10-10-4gb.img.xz" to boot a Pocket Beagle when flashed to an SD card using Etcher?And what should I expect when connected to a host system running macOS X?—
You are receiving this because you are subscribed to this thread.
Reply to this email directly, view it on GitHub, or mute the thread.

|  | Virus-free. www.avg.com  |

wcontello, 2017-10-14:
I am using a class 10 micro SD card from Lexar

metalheart, 2017-10-14:
I did the same mistake - thought that OSD soc has emmc and uncommented line with emmc flashing - it possibly fried my pocketbeagle. it does not boot anymore and there is no any output on UART0 pins. Did you managed to start board after flashing proper image?

wcontello, 2017-10-14:
I have not modified any files on the image.  Are you saying you think the image is not correct?

jadonk, 2017-10-16:
If the image is correct, this is likely an EEPROM issue. I will get an EEPROM programmer image.

wcontello, 2017-10-16:
I do not understand

> If the image is correct, this is likely an EEPROM issue. I will get an EEPROM programmer image.

Are you saying you can provide an image that will program an EEPROM on the Pocket Beagle?  Are you saying I should locate, download, and boot to am image that can program the EEPROM?

metalheart, 2017-10-17:
I found WP testpoint on board, does I2C is connected to EEPROM? Is there any information how to recover it? Also board has JTAG testpoints, could it be started under JTAG and access EEPROM IC?

jadonk, 2017-10-18:
Well, the program I use to write the EEPROMs is at https://gist.github.com/jadonk/809337ed8435cdc25f99887746550ed2. There's some instructions there on hacking an image to assume you are booting on a PocketBeagle. Ultimately, I need to break this down into something simpler for you. :-(

wcontello, 2017-10-18:
What if I do not have a BeagleBone Black?

wcontello, 2017-10-18:
Can you suppose how a Pocket Beagle shipped without the EEPROM properly programmed?

wcontello, 2017-10-18:
Can you trade me for the one I have?

yuvadm, 2017-10-19:
@wcontello You are spamming this issue, please take further communications on this topic offline.

ahbushnell, 2017-10-19:
Return it if it's defective.

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

wcontello, 2017-10-24:
Received another device and it booted perfectly.  I did return the other device

ahbushnell, 2017-10-24:
Great!

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

Closed 2017-09-25.

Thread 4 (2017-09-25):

GPIO44 is incorrectly labelled as GPIO48

jadonk, 2017-09-25:

mwelling, 2017-10-02:
@jadonk the latest pull request should fix the silkscreen issues on the Eagle and KiCAD designs.

Please confirm and merge or comment.

jadonk, 2017-10-02:
I need to also update the revision to "A2a" where the small 'a' indicates a non-critical change that doesn't require any additional validation.

mwelling, 2017-10-02:
@jadonk Okay. Can the Rev A2 be dropped from the KiCAD version altogether? With the latest commits the git revision is automatically stamped on the bottom silk when generating the gerbers.

jadonk, 2017-10-02:
Added "A2a" designation in 9e4b05ea3dfb566ee7537ca8b0c1815f43e819ca

Closed 2017-10-02.

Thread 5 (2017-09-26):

AUDIO Output

mbt28, 2017-09-26:
Hi,

Dont we have audio output with OSD3358?

Thanks

jadonk, 2017-09-27:
Not directly, though you could do something with the PWM.

Check out:
* https://shop.mikroe.com/mp3-click
* https://shop.mikroe.com/mic-click
* http://bela.io/ (needs additional wiring)

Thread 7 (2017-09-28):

'FAQ#How_do_I_get_connected_to_the_Internet' missing

easyw, 2017-09-28:
Hi,
in the Faq there is missing the "How_do_I_get_connected_to_the_Internet" part...
https://github.com/beagleboard/pocketbeagle/wiki/FAQ#How_do_I_get_connected_to_the_Internet

Is there any suggestion?

Thx

easyw, 2017-09-29:
What I would need is a PHY to be connected to the pocketbeagle module...

jadonk, 2017-10-02:
See the update on the FAQ page that includes connecting an Ethernet MAC/PHY via SPI. The Ethernet MII pins are not brought out on PocketBeagle and are reserved for you to use in your own re-spin of PocketBeagle.

easyw, 2017-10-05:
it would be nice if would possible to add this 10/100 BASE-TX ethernet adapter
https://shop.mikroe.com/eth-wiz-click
much better than the eth-click board, which is just a 10BASE-T adapter

Closed 2017-10-02.

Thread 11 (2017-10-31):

Incorrect pinout diagram label for P2_28 gpio

derekmulcahy, 2017-10-31:
The pinout image for the pocket beagle has the wrong GPIO pin number for P2_28. It is labelled as 124 but the pocket beagle schematic links it to MCASP0_AXR1. This pin is described on P36 of the data sheet as being gpio3_20. The math (3x32+20) would indicate that this is really pin 116.

The device tree has the correct mapping for P2_28.

`gpio = <0x160 0x14 0x0>;`

The 0x14 is an offset of 20. This mapping works fine with config-pin to toggle the P2_28 gpio.

derekmulcahy, 2017-11-01:
I also think the label for P1_33 should be GPIO 111 and not 110.

derekmulcahy, 2017-11-01:
Updated image attached with P1_33 = GPIO 111, P2_24 = GPIO 44, P2_28 = GPIO 116

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

jadonk, 2017-11-02:
P1_33 is labelled as as "1" under "PRU0" on the silkscreen. GPIO3.15 == GPIO111, so yes, it is GPIO111. Are you referencing something in the schematic? @derekmulcahy, which document is wrong??

jadonk, 2017-11-02:
Ah, that diagram. Thanks!

derekmulcahy, 2017-11-02:
Sorry, I didn't say it was on the Wiki FAQ page.

jadonk, 2017-11-02:
Did I get it all? https://github.com/beagleboard/pocketbeagle/commit/cc3af73758f25dcc473f226d1892a21de610f96f

derekmulcahy, 2017-11-02:
Yes, looks good.

jadonk, 2017-11-02:
OK, I should have it updated on the wiki now too.

Closed 2017-11-02.

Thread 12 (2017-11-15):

Wrong defaults in pinout diagram?

shirriff, 2017-11-15:
In the pinout diagram (PocketBeagle_pinout.png), do the dotted lines indicate the default mode? If so, the PRU defaults are wrong (P1_29/31/33/35 and P2_28/30/32/34).

I checked the latest Stretch IoT build (Linux beaglebone 4.4.91-ti-r133 #1 SMP Tue Oct 10 05:18:08 UTC 2017 armv7l GNU/Linux) and these pins come up in GPIO mode, not PRU.

jadonk, 2017-12-06:
@RobertCNelson can you make sure the default modes match the silkscreen in all of the images? The device tree I provided made "default" be the mode that is documented as the default. This will help with many newb issues.

RobertCNelson, 2017-12-07:
@shirriff and @jadonk correct pinmux's should now be avaialbe in:

```
4.4.91-ti-r138 (building)
4.9.67-ti-r82 (building)
4.14.4-ti-r15 (building)
4.14.4-bone7 (building)
&
4.15.0-rc3 (sunday)
```
and the matching config-pin will be:
```
bb-cape-overlays_4.4.20171207.0-0rcnee1
```
https://github.com/beagleboard/bb.org-overlays/commit/0013331fd0fe49b90af5a57944ef854283ab1d70

Regards,

Closed 2018-01-01.

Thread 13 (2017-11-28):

GPIO 44 labelled as 48 in silkscreen

brucepom, 2017-11-28:
Thanks for an amazing board!

In my testing the pin labelled as 48 in the silkscreen is actually accessed as pin 44.

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

I haven't found an official pinout illustration for PocketBeagle but I did find this one: http://files.linuxgizmos.com/bboard_pocketbeagle_pinout.jpg I'm unsure of the original source of this image but the image also describes that pin as 44.

RobertCNelson, 2017-11-28:
@brucepom correct it's pin 44:

https://github.com/beagleboard/pocketbeagle/issues/4

https://github.com/beagleboard/pocketbeagle/wiki/FAQ#What_is_the_pinout_for_the_expansion_headers

Regards,

mwelling, 2017-11-28:
This has already been corrected on the design files. Guessing that when the next production run commences they will update them. Might be a while though.

https://github.com/beagleboard/pocketbeagle/pull/8

brucepom, 2017-11-29:
Thanks guys, looks like you were already on top of it. Really appreciate all your work.

Closed 2017-12-06.

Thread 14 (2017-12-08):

PinOut Names not working correctly

el-j, 2017-12-08:
first of all: really nice board! thank you!

i have a problem with bonescript and the pin names. i try to use the gpio pins from p2.
after a frustrating time where nothing worked with the board. i figured out that i have to update the bonescript module with the latest release from github. (it was not integrated in the lastest debian image)

now i am able to use the "P1_xx" "P2_xx" declaration for the pins without getting just an error.
sadly it does not work properly for all pins, from my testing.

the pin P2_2 and P2_8 working correctly with a pushbutton.
but the pins P2_4 + 6 + 10 do not get any input with the same code.

i try to find the answer with the getPinMode methode but i cannot get a clue out of it.

not working:
```
{ pin: 'P2_6',
  name: 'GPIO1_25',
  options:
   [ 'gpmc_wpn',
     'gmii2_rxer',
     'gpmc_csn5',
     'rmii2_rxer',
     'mmc2_sdcd',
     'pr1_mii1_txen',
     'uart4_txd',
     'gpio1_25' ],
  gpio: { active: true, direction: 'in', allocated: false } }
mux = undefined
pullup = undefined
slew = undefined
gpio = [object Object]
options = gpmc_wpn,gmii2_rxer,gpmc_csn5,rmii2_rxer,mmc2_sdcd,pr1_mii1_txen,uart4_txd,gpio1_25
pin = P2_6
name = GPIO1_25
err = undefined
```
working:
```
{ pin: 'P2_8',
  name: 'GPIO1_28',
  options:
   [ 'gpmc_ben1',
     'mii2_col',
     'NA',
     'mmc2_dat3',
     'NA',
     'NA',
     'mcasp0_aclkr',
     'gpio1_28' ],
  gpio: { active: true, direction: 'in', allocated: false } }
mux = undefined
pullup = undefined
slew = undefined
gpio = [object Object]
options = gpmc_ben1,mii2_col,NA,mmc2_dat3,NA,NA,mcasp0_aclkr,gpio1_28
pin = P2_8
name = GPIO1_28
err = undefined
```
do you have any idea what i can do, to use this pins?

jadonk, 2017-12-19:
```sh
$ sudo npm install -g --unsafe-perm bonescript@beta
[sudo] password for debian:
npm WARN deprecated coffee-script@1.9.1: CoffeeScript on NPM has moved to "coffeescript" (no hyphen)

> ref@1.3.5 install /usr/local/lib/node_modules/bonescript/node_modules/ref
> node-gyp rebuild

make: Entering directory '/usr/local/lib/node_modules/bonescript/node_modules/ref/build'
  CXX(target) Release/obj.target/binding/src/binding.o
  SOLINK_MODULE(target) Release/obj.target/binding.node
  COPY Release/binding.node
make: Leaving directory '/usr/local/lib/node_modules/bonescript/node_modules/ref/build'
- graceful-readlink@1.0.1 node_modules/bonescript/node_modules/graceful-readlink
/usr/local/lib
└─┬ bonescript@0.6.2-beta2
  ├─┬ express@4.13.4
  │ ├─┬ accepts@1.2.13
  │ │ └─┬ mime-types@2.1.17
  │ │   └── mime-db@1.30.0
  │ ├── content-type@1.0.4
  │ ├── depd@1.1.1
  │ ├── parseurl@1.3.2
  │ └─┬ proxy-addr@1.0.10
  │   └── forwarded@0.1.2
  ├─┬ ffi@2.0.0
  │ └── ref@1.3.5
  ├─┬ serialport@3.1.2
  │ ├── commander@2.12.2
  │ └─┬ object.assign@4.0.4
  │   └── function-bind@1.1.1
  └─┬ winston@2.1.1
    └── stack-trace@0.0.10

$ DEBUG=true node -pe "require('bonescript').getPinMode('P2_6')"      
4:4:91-ti-r133
Using Mainline interface
debug: index.js loaded
debug: getPinMode(P2_6);
debug: getPinMode(P2_6): Error: EACCES: permission denied, open '/sys/kernel/debug/pinctrl/44e10800.pinmux/pins'
{ pin: 'P2_6',
  name: 'GPIO1_25',
  options:
   [ 'gpmc_wpn',
     'gmii2_rxer',
     'gpmc_csn5',
     'rmii2_rxer',
     'mmc2_sdcd',
     'pr1_mii1_txen',
     'uart4_txd',
     'gpio1_25' ],
  gpio: { allocated: false } }
debug: Calling run()

Exiting Cleanly
Unable to open /dev/mem
Unable to open /dev/mem
ERROR: trying to disable motors before they have been initialized
Unable to open /dev/mem
Unable to open /dev/mem
Unable to open /dev/mem
$ DEBUG=true sudo node -pe "require('bonescript').getPinMode('P2_6')" 
{ pin: 'P2_6',
  name: 'GPIO1_25',
  options:
   [ 'gpmc_wpn',
     'gmii2_rxer',
     'gpmc_csn5',
     'rmii2_rxer',
     'mmc2_sdcd',
     'pr1_mii1_txen',
     'uart4_txd',
     'gpio1_25' ],
  gpio: { allocated: false },
  mux: 7,
  slew: 'fast',
  rx: 'enabled',
  pullup: 'pullup' }

Exiting Cleanly
ERROR: trying to disable motors before they have been initialized
$ DEBUG=true node -pe "require('bonescript').getPinMode('P2_8')"
4:4:91-ti-r133
Using Mainline interface
debug: index.js loaded
debug: getPinMode(P2_8);
debug: getPinMode(P2_8): Error: EACCES: permission denied, open '/sys/kernel/debug/pinctrl/44e10800.pinmux/pins'
{ pin: 'P2_8',
  name: 'GPIO1_28',
  options:
   [ 'gpmc_ben1',
     'mii2_col',
     'NA',
     'mmc2_dat3',
     'NA',
     'NA',
     'mcasp0_aclkr',
     'gpio1_28' ],
  gpio: { allocated: false } }
debug: Calling run()

Exiting Cleanly
Unable to open /dev/mem
Unable to open /dev/mem
ERROR: trying to disable motors before they have been initialized
Unable to open /dev/mem
Unable to open /dev/mem
Unable to open /dev/mem
```

So, it seems P2_8 and P2_6 have the same issue, which is the pinmux setting cannot be read without being superuser.

jadonk, 2017-12-19:
Possible fix:

```
# /etc/udev/rules.d/83-pinmux-noroot.rules
#
# Change group to gpio
KERNEL=="44e10800.pinmux", PROGRAM="/bin/sh -c '/bin/chown -R root:gpio /sys/kernel/debug/pinctrl/44e10800.pinmux'"
# Change user permissions to ensure user and group have read/write permissions
KERNEL=="44e10800.pinmux", PROGRAM="/bin/sh -c '/bin/chmod ugo+x /sys/kernel/debug; /bin/chmod -R ug+rw /sys/kernel/debug/pinctrl/44e10800.pinmux'"
```

jadonk, 2017-12-19:
This is really a BoneScript (and Debian image) issue, not PocketBeagle hardware, so I've opened an issue on BoneScript and will close this one.

RobertCNelson, 2017-12-20:
Doh! Bonescript goes thru the /sys/kernel/debug/ interface!  i just had gpio user setup on /sys/class/gpio.. okay i'll patch bb-customization with the new udev rule...

Closed 2017-12-19.

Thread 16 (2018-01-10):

C6 on silkscreen is C7 on schematic

sirkha, 2018-01-10:
I thought that C7 seemed awfully far away from P1_17 and P1_18, so I checked. On the [SiP B OSD3358 SiP JTAG, USB & Analog Signals](https://github.com/beagleboard/pocketbeagle/wiki/images/SiP-B-sch.png), C7 probes out to where [C6 is on the silkscreen, right next to the SIP](https://github.com/beagleboard/pocketbeagle/wiki/images/21fig-PB-walkaround.png).

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

jadonk, 2018-01-23:
I confirmed the existing silkscreen is correct with regards to C6 and C7. Both capacitors have GND on one side and a supply rail on the other (for decoupling). Perhaps you experienced some bleed-over between the supply rails? [Careful with this, you might damage the device.] You might try measuring the voltages instead of looking at continuity. You should C6 have 3.3V across it and C7 have 1.8V across it.

Also, you can tell visually that C6 is the larger capacity simply by the size, so that should be a good indicator for you. I looked at the traces on the GERBERs and they go to the proper places without shorts, so I'm confident there is no issue here.

mwelling, 2018-01-24:
Besides the sub-optimal placement of C7. :)

Closed 2018-01-23.

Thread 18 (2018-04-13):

4.14 bus error

tesorrells, 2018-04-13:
Previously I was using kernel 4.4 where I was pulling data from an mcp3004 ADC. It worked fine with uio_pruss and setting the pins, but when I upgraded to kernel 4.14 I started getting bus errors. It isn't my wiring or any of my scripts because they are all  exactly the same between both kernels. I recompiled everything to see if it might be that, but that didn't work either. Is there something that changed between kernels that I should be looking at?

tesorrells, 2018-05-15:
Updating to 4.16 solved this.

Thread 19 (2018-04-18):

Can't boot from SD card

iSsO, 2018-04-18:
I think my board is booting from the wrong mmc

I've downloaded the latest image from http://beagleboard.org/latest-images for pocketbeagle named Debian 9.3 2018-03-05 4GB SD IoT, then flashed the image to an 8gb sd card using etcher. The board refuses to boot after inserting the card and powering it.

Only the blue PWR led is on, and the octavo chip gets hot.

When I connected a serial monitor to UART0, I found that it is trying to boot from MMC1 not MMC0 (the SD card)
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

jadonk, 2018-05-20:
@beagleboard/kernel-contributors Is this a case of a bad board or, more likely in my view, a bad SD card?

@iSsO can you try a different SD card?

iSsO, 2018-06-14:
I've tried different images and SD cards with the same result.

Could it be a problem with the EEPROM?

jadonk, 2018-06-22:
Do you have a Linux host? Can you try: https://elinux.org/images/b/b2/Netconsole.pdf http://bbb.io/pbncgist ?

jadonk, 2018-07-10:
Unclear if it can be fixed. Depends if the problem is in the SIP or on the board. We have a way to boot it via USB using node-beagle-boot.

https://schd.ws/hosted_files/elciotna18/42/netconsole.pdf
https://www.youtube.com/watch?v=9CxfKfjykz4

You can then login and do various tests on the MMC interface. You could probably change the device tree to make it SPI-mode.

Anyway, the above is mostly FYI on how we'd do any failure analysis. Maybe best to contact me via my e-mail address listed at bbb.io/about and we'll work with distributor and manufacturer to get you a replacement.

iSsO, 2018-07-15:
Thanks Jason, thanks for the NetConsole stuff, I didn't know that existed!

I'll close the issue for now, will contact you if I need additional assistance.

Closed 2018-07-15.

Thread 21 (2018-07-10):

issue about the CAN Bus of Pocketbeagle

zerulin, 2018-07-10:
Please can anybody help me? I try to use the can bus with SN65HVD230 can module. I enable the can pins by:
config-pin P2_09 can
config-pin P2_11 can
And then I test loopback, it works. But if I try to communicate with other CAN module, there are no data transmitted or received when I check with ifconfig can0. ( I also try with other CAN pins, but it still cannot work). Do I need other configuration or what' wrong with my operation?

zerulin, 2018-07-10:
BTW, I use the newest Debian 9.4

zerulin, 2018-07-10:
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
This is one of my connection, the module is https://www.waveshare.com/sn65hvd230-can-board.htm
I will test again and attach the images of commands

zerulin, 2018-07-10:
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
This is loopback test, it works.
But if I off the loopback mode, and try to send data, there is no data send via Tx when I check ifconfig can0:
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

zerulin, 2018-07-10:
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
Debian version I use

mwelling, 2018-07-10:
Are you connecting the CAN transceiver to another CAN device?

zerulin, 2018-07-10:
:( ， I connect to another BB Black with CAN CAPE. I have test the BB Black +CAPE x2, they are work, and if I change to the Pocketbeagle, It failed.

jadonk, 2019-01-09:
Can you try a different PHY?

https://spin.atomicobject.com/2017/05/06/troubleshooting-can-bus-communication-subaru/

Jabed-Akhtar, 2021-11-24:
In my case, I am not using CAN-transceiver at all, and I am able to monitor CAN-Messages over the wire. But I am not able to send out CAN-Messages. Could it be because of not using CAN-Transceiver? Can anyone please provide me any Datasheet or any Document, where I can see how the CAN is built in PocketBeagle!
Some more questions:
> Is CAN-Transceiver build-in inside the PocketBegle?
> Is the 120Ohm for CAN also build-in inside the PocketBegle?

Tanmay-FuelDaddy, 2023-05-23:
I too would appreciate an answer to  jabed's Questions

gletchm, 2023-05-23:
I am pretty sure you need the transceiver. The CAN bus in a 2 wire differential bus. In my experience that CAN peripheral in the chip, expects to connected to a CAN transceiver. I can see how receiving CAN message could work, sending is a lot different. You have to control the signaling correctly. They make CAN transceiver that will work with 3.3V, if that is the issue. Here is a link to some good info: https://www.beyondlogic.org/adding-can-to-the-beaglebone-black/

Jabed-Akhtar, 2023-06-07:
> I am pretty sure you need the transceiver. The CAN bus in a 2 wire differential bus. In my experience that CAN peripheral in the chip, expects to connected to a CAN transceiver. I can see how receiving CAN message could work, sending is a lot different. You have to control the signaling correctly. They make CAN transceiver that will work with 3.3V, if that is the issue. Here is a link to some good info: https://www.beyondlogic.org/adding-can-to-the-beaglebone-black/

Thank you so much :)

RobertPHeller, 2023-06-25:
Have a look at https://github.com/RobertPHeller/LCC-PNET-Router for a board that connects to both CAN IFs on a PocketBeagle. One CAN IF (can0) connects to LCC's CAN Network and the other CAN IF (can1) connects to Pricom PNET.  This board works properly (I have some boards make and have tested it).

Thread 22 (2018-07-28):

System Reference Manual pin 48 or 44?

pakair, 2018-07-28:
Fig. 41 shows the P2 header +3.3V as pin 48 but the next image Fig. 42 shows it as 44 (pin 24 of the P2)
which is it? thanks.

fivdi, 2018-07-28:
See https://github.com/beagleboard/pocketbeagle/issues/13 and https://github.com/beagleboard/pocketbeagle/issues/4.

That being said, 3.3V is on P2_23 and not on P2_24.

Closed 2019-01-09.

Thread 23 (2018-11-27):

Low battery monitoring?

Vontux, 2018-11-27:
Is there a way to query for the battery status, either a low battery message or voltage output?

jadonk, 2019-01-09:
There is an on-board ADC. You can use a resistor divider to monitor the voltage output from the battery.

Closed 2019-01-09.

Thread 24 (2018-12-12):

Pocketbeagle not booting from SD card

MariusTOR, 2018-12-12:
I'm trying to evaluate a PocketBeagle (rev A2) for use in an instrumentation class I'm teaching this Spring, however, the one I have refuses to boot.  I just purchased it from Arrow, and the microSD card that I'm using to boot it has never had anything else written to it (save by the manufacturer).

Using the Etcher program suggested by the quick start guide, I've burned a 16GB microSD card once with the image for Debian Linux v9.5 and, after that failed, with Debian Linux v9.1.  Both times, the only change I've done is to edit /boot/uEnv.txt as directed to make sure that cmdline=init=/opt/scripts/tools/eMMC/init-eMMC-flasher-v3.sh is uncommented.

Booting with Debian v9.1
Upon plugging in the PB to USB, all 4 LEDs light up momentarily.  They all go off, and USR0 starts its heartbeat pattern.  USR1 starts to blink intermittantly and the Octavo chip starts to heat up.  After about 5 seconds, all four LEDs light up simultaneously.  I let it stay that way for 5-10 more seconds before the Octavo chip gets too warm and unplug the USB.

Booting with Debian v9.5
1 - Upon plugging in the PB to USB, all 4 LEDs light up momentarily.
2 - They all go off, and USR0 starts its heartbeat pattern and USR2 is on.  USR1 starts to blink intermittantly.
3 - After about 20 seconds, USR2 blinks quickly and intermittently while being dim, USR1 stays off, and USR0 continues its heartbeat pattern.
4 - The Octavo chip is starting to get warm.  I let it stay that way for 30 more seconds and unplug the USB.

In neither case does the board get recognized from a computer running Ubuntu 16.10.  Attempts to browse to the board by going to 192.168.6.2 (while booting with Debian v9.5) failed, but resulted in all 4 LEDs lighting up simultaneously after step 2 of the aforementioned boot process.

I'm at quite a loss as to how to proceed.  Any help would be appreciated.

mwelling, 2018-12-12:
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

There is no eMMC on the PocketBeagle so this line should remain commented.

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

Just recomment the line mention above and see if that helps.

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

--
Michael Welling

Embedded System Architect / Founder
QWERTY Embedded Design, LLC - www.qwertyembedded.com

MariusTOR, 2018-12-12:
No good -- I recommented that line and bootup behavior is exactly the same as before.

mwelling, 2018-12-13:
Try reflashing the image to the MicroSD from scratch and plugging it in without modification.

MariusTOR, 2018-12-13:
Found the problem -- I was using a USB cord that only had wires for power, not data.  Thanks!

mwelling, 2018-12-13:
No problem.

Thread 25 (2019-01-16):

Pocketbeagle not booting from SD card (but is visible on USB without the SDCARD)

nutilius, 2019-01-16:
Hello everybody.
Yesterday I receiver PockedBeagle from Farnell and try to boot from SD card. Only Power LED is on, the rest is dead. I have tried 5 different cards with different size and 3 diffrent USB cables.
System is dead. Whe system has card included, on attached linux system there is no USB device (no messages in dmesg also). I've tried two diffrent official Debian images from - current and last previous.
**When  I remove the card** and again attach board, I see new device  named Texas Instruments and dmesg also presents messages about new device.

jadonk, 2019-01-16:
@nutilius The boot image is bad. The device has a USB boot mode in ROM, which is why you'd see it on your computer even without a valid boot image. You can possibly use BeagleBoot.

What steps are you following to program the microSD card?

nutilius, 2019-01-16:
@jadonk Downloaded image was written to SD card by dd tool and later sync command was executed.

nutilius, 2019-01-16:
Of course after decompressing using xz and veryfing checksum.

nutilius, 2019-02-27:
The new part works good. Probably previous was damaged.

Closed 2019-02-27.

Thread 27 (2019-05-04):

Installing gspread error

omarcs22, 2019-05-04:
I am currently running my pocketbeagle with  Debian 9.5 2018-10-07 4GB SD IoT,
I have tried a couple of tatorials on how to install gspread with no luck.
I get this error when I run "sudo install pip3 gspread" in the Lenix  terminal window using putty.exe

debian@beaglebone:~$ sudo pip3 install gspread
[sudo] password for debian:
Collecting gspread
Exception:
Traceback (most recent call last):
  File "/usr/share/python-wheels/urllib3-1.19.1-py2.py3-none-any.whl/urllib3/connection.py", line 138, in _new_conn
    (self.host, self.port), self.timeout, **extra_kw)
  File "/usr/share/python-wheels/urllib3-1.19.1-py2.py3-none-any.whl/urllib3/util/connection.py", line 75, in create_connection
    for res in socket.getaddrinfo(host, port, family, socket.SOCK_STREAM):
  File "/usr/lib/python3.5/socket.py", line 733, in getaddrinfo
    for res in _socket.getaddrinfo(host, port, family, type, proto, flags):
socket.gaierror: [Errno -3] Temporary failure in name resolution

During handling of the above exception, another exception occurred:

Traceback (most recent call last):
  File "/usr/share/python-wheels/urllib3-1.19.1-py2.py3-none-any.whl/urllib3/connectionpool.py", line 594, in urlopen
    chunked=chunked)
  File "/usr/share/python-wheels/urllib3-1.19.1-py2.py3-none-any.whl/urllib3/connectionpool.py", line 350, in _make_request
    self._validate_conn(conn)
  File "/usr/share/python-wheels/urllib3-1.19.1-py2.py3-none-any.whl/urllib3/connectionpool.py", line 837, in _validate_conn
    conn.connect()
  File "/usr/share/python-wheels/urllib3-1.19.1-py2.py3-none-any.whl/urllib3/connection.py", line 281, in connect
    conn = self._new_conn()
  File "/usr/share/python-wheels/urllib3-1.19.1-py2.py3-none-any.whl/urllib3/connection.py", line 147, in _new_conn
    self, "Failed to establish a new connection: %s" % e)
requests.packages.urllib3.exceptions.NewConnectionError: <requests.packages.urllib3.connection.VerifiedHTTPSConnection object at 0xb5e20a70>: Failed to establish a new connection: [Errno -3] Temporary failure in name resolution

During handling of the above exception, another exception occurred:

Traceback (most recent call last):
  File "/usr/lib/python3/dist-packages/pip/basecommand.py", line 215, in main
    status = self.run(options, args)
  File "/usr/lib/python3/dist-packages/pip/commands/install.py", line 353, in run
    wb.build(autobuilding=True)
  File "/usr/lib/python3/dist-packages/pip/wheel.py", line 749, in build
    self.requirement_set.prepare_files(self.finder)
  File "/usr/lib/python3/dist-packages/pip/req/req_set.py", line 380, in prepare_files
    ignore_dependencies=self.ignore_dependencies))
  File "/usr/lib/python3/dist-packages/pip/req/req_set.py", line 554, in _prepare_file
    require_hashes
  File "/usr/lib/python3/dist-packages/pip/req/req_install.py", line 278, in populate_link
    self.link = finder.find_requirement(self, upgrade)
  File "/usr/lib/python3/dist-packages/pip/index.py", line 465, in find_requirement
    all_candidates = self.find_all_candidates(req.name)
  File "/usr/lib/python3/dist-packages/pip/index.py", line 423, in find_all_candidates
    for page in self._get_pages(url_locations, project_name):
  File "/usr/lib/python3/dist-packages/pip/index.py", line 568, in _get_pages
    page = self._get_page(location)
  File "/usr/lib/python3/dist-packages/pip/index.py", line 683, in _get_page
    return HTMLPage.get_page(link, session=self.session)
  File "/usr/lib/python3/dist-packages/pip/index.py", line 792, in get_page
    "Cache-Control": "max-age=600",
  File "/usr/share/python-wheels/requests-2.12.4-py2.py3-none-any.whl/requests/sessions.py", line 501, in get
    return self.request('GET', url, **kwargs)
  File "/usr/lib/python3/dist-packages/pip/download.py", line 386, in request
    return super(PipSession, self).request(method, url, *args, **kwargs)
  File "/usr/share/python-wheels/requests-2.12.4-py2.py3-none-any.whl/requests/sessions.py", line 488, in request
    resp = self.send(prep, **send_kwargs)
  File "/usr/share/python-wheels/requests-2.12.4-py2.py3-none-any.whl/requests/sessions.py", line 609, in send
    r = adapter.send(request, **kwargs)
  File "/usr/share/python-wheels/CacheControl-0.11.7-py2.py3-none-any.whl/cachecontrol/adapter.py", line 47, in send
    resp = super(CacheControlAdapter, self).send(request, **kw)
  File "/usr/share/python-wheels/requests-2.12.4-py2.py3-none-any.whl/requests/adapters.py", line 423, in send
    timeout=timeout
  File "/usr/share/python-wheels/urllib3-1.19.1-py2.py3-none-any.whl/urllib3/connectionpool.py", line 643, in urlopen
    _stacktrace=sys.exc_info()[2])
  File "/usr/share/python-wheels/urllib3-1.19.1-py2.py3-none-any.whl/urllib3/util/retry.py", line 315, in increment
    total -= 1
TypeError: unsupported operand type(s) for -=: 'Retry' and 'int'

playaspec, 2020-05-09:
You're better off using the appropriate Linux forum. Any issues here are likely ONLY for hardware design and documentation issues.

mwelling, 2020-05-09:
The problem is related to not having an internet connection on the device.

https://www.digikey.com/en/maker/blogs/how-to-connect-a-beaglebone-black-to-the-internet-using-usb

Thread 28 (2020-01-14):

Pin 36 is missing from P2 Header connections table in the system reference manual.

patrickwalton, 2020-01-14:
Pin 35 is in there twice, but I'm not seeing pin 36

jadonk, 2023-09-19:
Check this version of the table/SRM: https://docs.beagleboard.org/latest/boards/pocketbeagle/original/ch07.html#id10

Closed 2023-09-19.

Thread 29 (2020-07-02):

Question on Beaglebone pocket project

kissup77, 2020-07-02:
We tried to duplicate your pocket Hardware.
Our produced board:
When power is connected, only one LED comes up
Original Pocket Beagle:
When power is connected, only one LED comes up and then other 4 LEDs are up sequencially.

Should we fuse ROM? or EEPROM? to boot it up?
and how to?
Can you share the link if there is any guide for it?

mwelling, 2020-07-02:
You will need the "flasher" image to program the EEPROM and a shunt to enable writing.

https://beagleboard.org/latest-images

Check issue resolved issue #3 here: https://github.com/beagleboard/pocketbeagle/issues/3

mwelling, 2020-07-02:
Another route would be to modify the bootloader such that it doesn't rely on the EEPROM to boot.

kissup77, 2020-07-02:
Can I know what Another route is ? (Physical connection or jumper ?)

mwelling, 2020-07-02:
It is a purely firmware route. The standard Beagleboard U-Boot uses the EEPROM to determine the board type. You can disable this detection and boot whatever you want. This off course requires some firmware chops and understanding of U-Boot.

mwelling, 2020-07-02:
The "flasher" image will boot the board without the EEPROM program as it has a hack in the bootloader already to fall back to defaults for booting the pocketbeagle.

kissup77, 2020-07-03:
I had tried original flash image fused tf card chip, still not booting up. So for beagle newbie, it is recommendable to fuse eeprom?

kissup77, 2020-07-03:
Please tell me how to flash to EEPROM.

mwelling, 2020-07-03:
You need to boot the flasher image in order to program the EEPROM.

If you have access to the debug UART check if you have output there. If not you might have deeper issues.

kissup77, 2020-07-06:
`board_name=[A335BLNK] ...
30 bytes read in 29 ms (1000 Bytes/s)
Loaded environment from /boot/.eeprom.txt
Setting bus to 0
0000: ff ff ff ff ff ff ff ff ff ff ff ff ff ff ff ff    ................
0010: ff ff ff ff ff ff ff ff ff ff ff ff ff ff ff ff    ................
Setting bus to 0
Setting bus to 0
Setting bus to 0
0000: ff ff ff ff ff ff ff ff ff ff ff ff ff ff ff ff    ................
0010: ff ff ff ff ff ff ff ff ff ff ff ff ff ff ff ff    ................
resetting ...

U-Boot SPL 2019.04-00003-g2bf638a03e (Mar 06 2020 - 11:25:08 -0600)
Trying to boot from MMC1
Loading Environment from EXT4... ** File not found /boot/uboot.env **

** Unable to read "/boot/uboot.env" from mmc0:1 **

U-Boot 2019.04-00003-g2bf638a03e (Mar 06 2020 - 11:25:08 -0600), Build: jenkins-github_Bootloader-Builder-137

CPU  : AM335X-GP rev 2.1
I2C:   ready
DRAM:  512 MiB
No match for driver 'omap_hsmmc'
No match for driver 'omap_hsmmc'
Some drivers were not found
Reset Source: Global warm SW reset has occurred.
Reset Source: Power-on reset has occurred.
RTC 32KCLK Source: External.
MMC:   OMAP SD/MMC: 0, OMAP SD/MMC: 1
Loading Environment from EXT4... ** File not found /boot/uboot.env **

** Unable to read "/boot/uboot.env" from mmc0:1 **
<ethaddr> not set. Validating first E-fuse MAC
BeagleBone: cape eeprom: i2c_probe: 0x54:
BeagleBone: cape eeprom: i2c_probe: 0x55:
BeagleBone: cape eeprom: i2c_probe: 0x56:
BeagleBone: cape eeprom: i2c_probe: 0x57:
Net:   usb_ether
Press SPACE to abort autoboot in 2 seconds`

I am getting this error.

kissup77, 2020-07-06:
Another question from earlier answer:
It is a purely firmware route. The standard Beagleboard U-Boot uses the EEPROM to determine the board type. You can disable this detection and boot whatever you want. This off course requires some firmware chops and understanding of U-Boot.
==> 1. Can you share the link how to disable detection?
==> 2. How to boot with SD card?

mwelling, 2020-07-07:
1) There are some pointers here:
https://octavosystems.com/app_notes/osd335x-eeprom-during-boot/

2) You are booting SD if you have U-Boot coming up.
Remember you have to GND the WP pin which writing to EEPROM.

kissup77, 2020-07-08:
Thank you.
Solved.

kissup77, 2020-07-09:
I can't find the WP pin of the Beagle Board Black wireless and Beagle Board AI.
Is there anything I have to do to write the EEPROM?

mwelling, 2020-07-09:
The BBBW has an external EEPROM and WP test pad for pulling it to ground.
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

The BBAI is special creature using the newer AM5728/9. I don't think has an EEPROM.

kissup77, 2020-07-13:
I had duplicated beagle pocket board and 1 board is working fine with your suggestion(WP to GND) while other 4 boards does not come up.
in pocket beagle EMU0 (MISC EMULATION PIN) is not going up to 3.3V while normal board goes up to 3.3V.
What might cause this issue?
Any suggestion?

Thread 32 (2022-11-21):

Graphics out

SinanAkkoyun, 2022-11-21:
Hello!
I need to add an HDMI output to the pocketbeagle. (even if it requires a chip like the NXP TDA)

How can I go about that and how could I make it work with linux?
Thank you so much!

mwelling, 2022-11-21:
Are you designing a new board based on the SiP or just trying to design an adapter for the PocketBeagle?

PocketBeagle does not break out all of the SiP's LCD display lines to headers you would need a display adapter from the available peripherals. USB might be able to do it but it won't be particularly performant.

If you are making a new board based on the SiP you can leverage the design from other Beagles (if you can source the chips):
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

SinanAkkoyun, 2023-01-04:
I want to design a new board based on the SiP and reflow the chip from a pocket beagle

Thank you so much for the provided schematic!

Closed 2023-09-19.

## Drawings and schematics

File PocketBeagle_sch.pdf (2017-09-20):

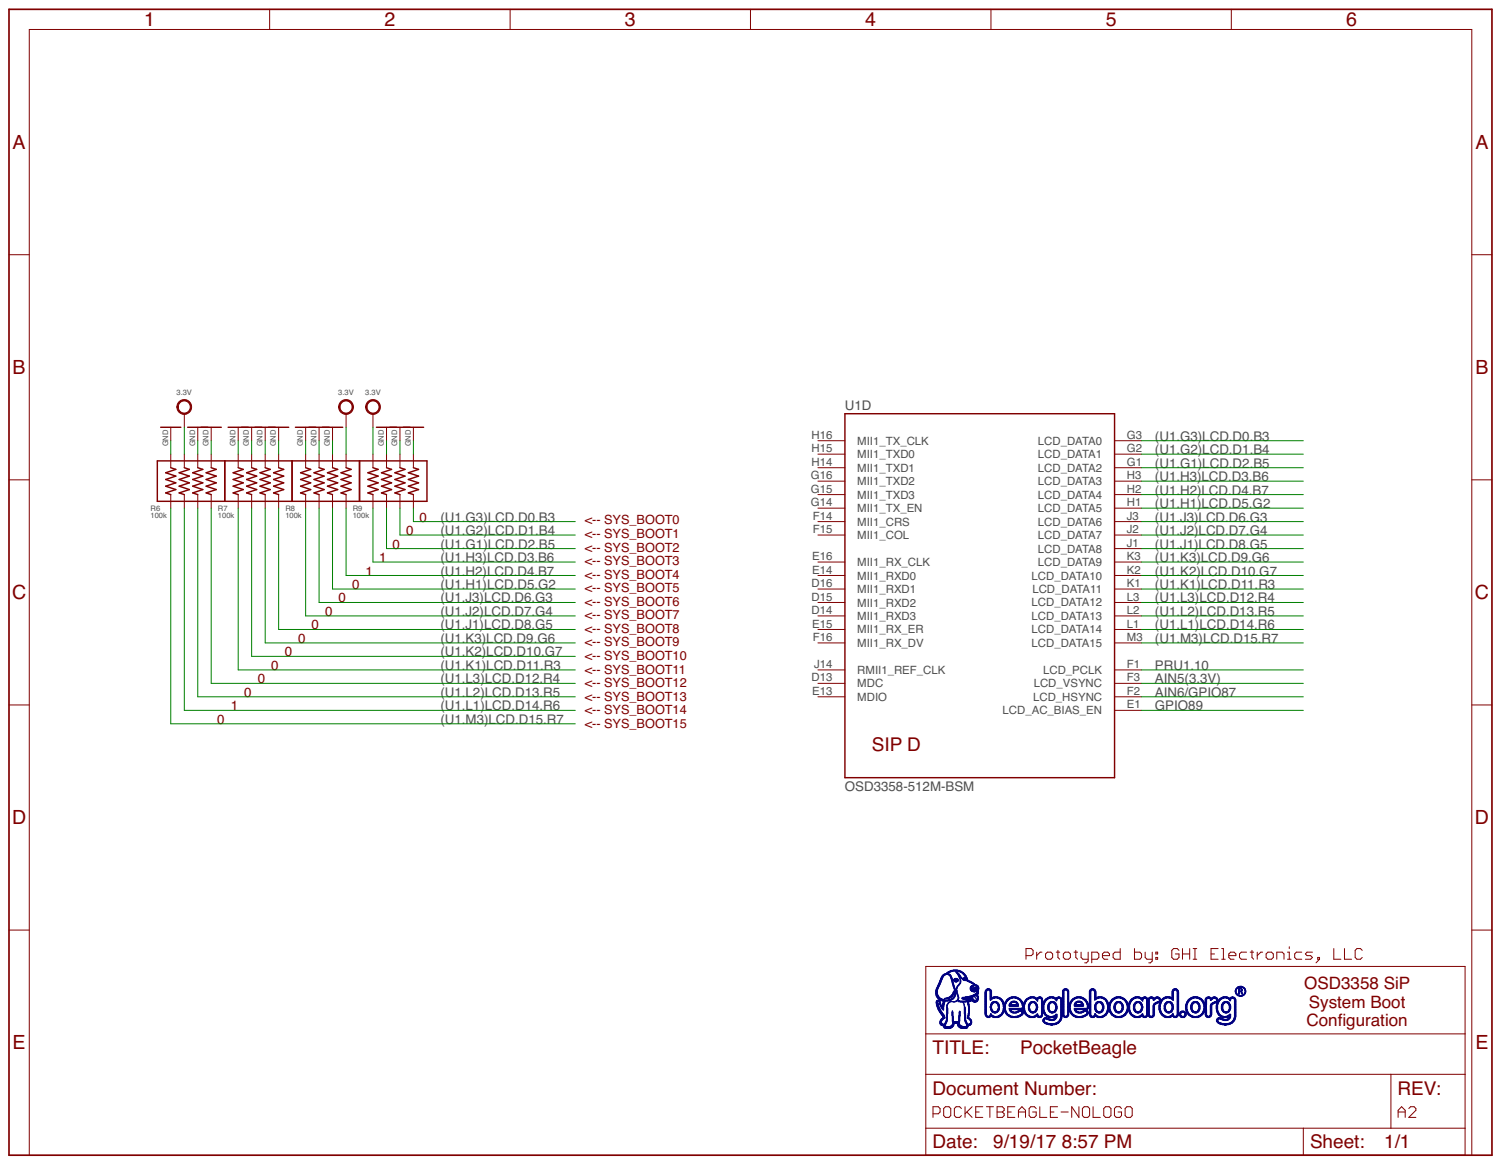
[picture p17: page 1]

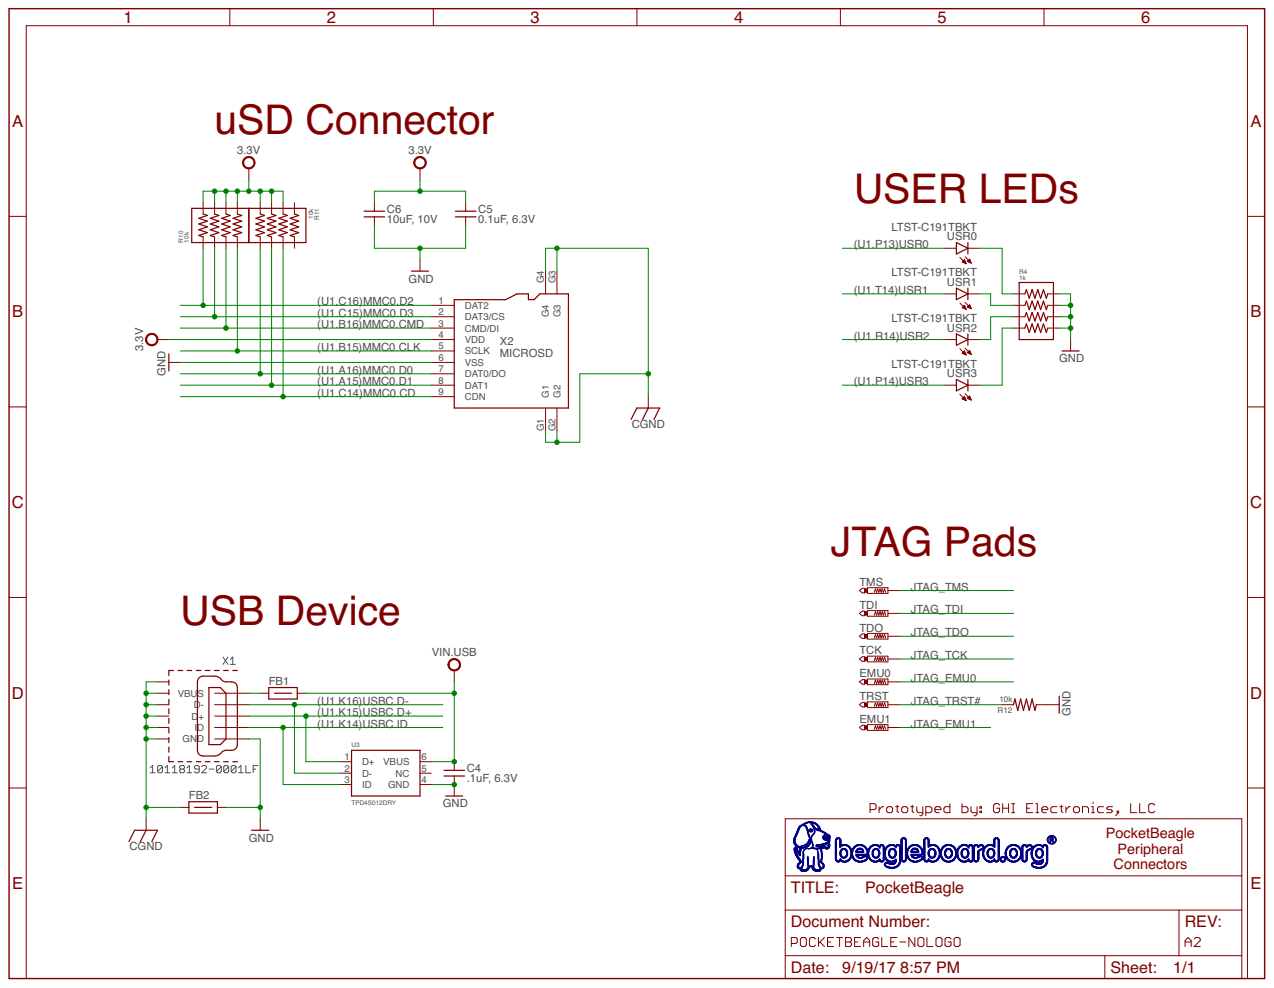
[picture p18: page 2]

C | VIN.USB | C

D | TDI JTAG_TDI | D

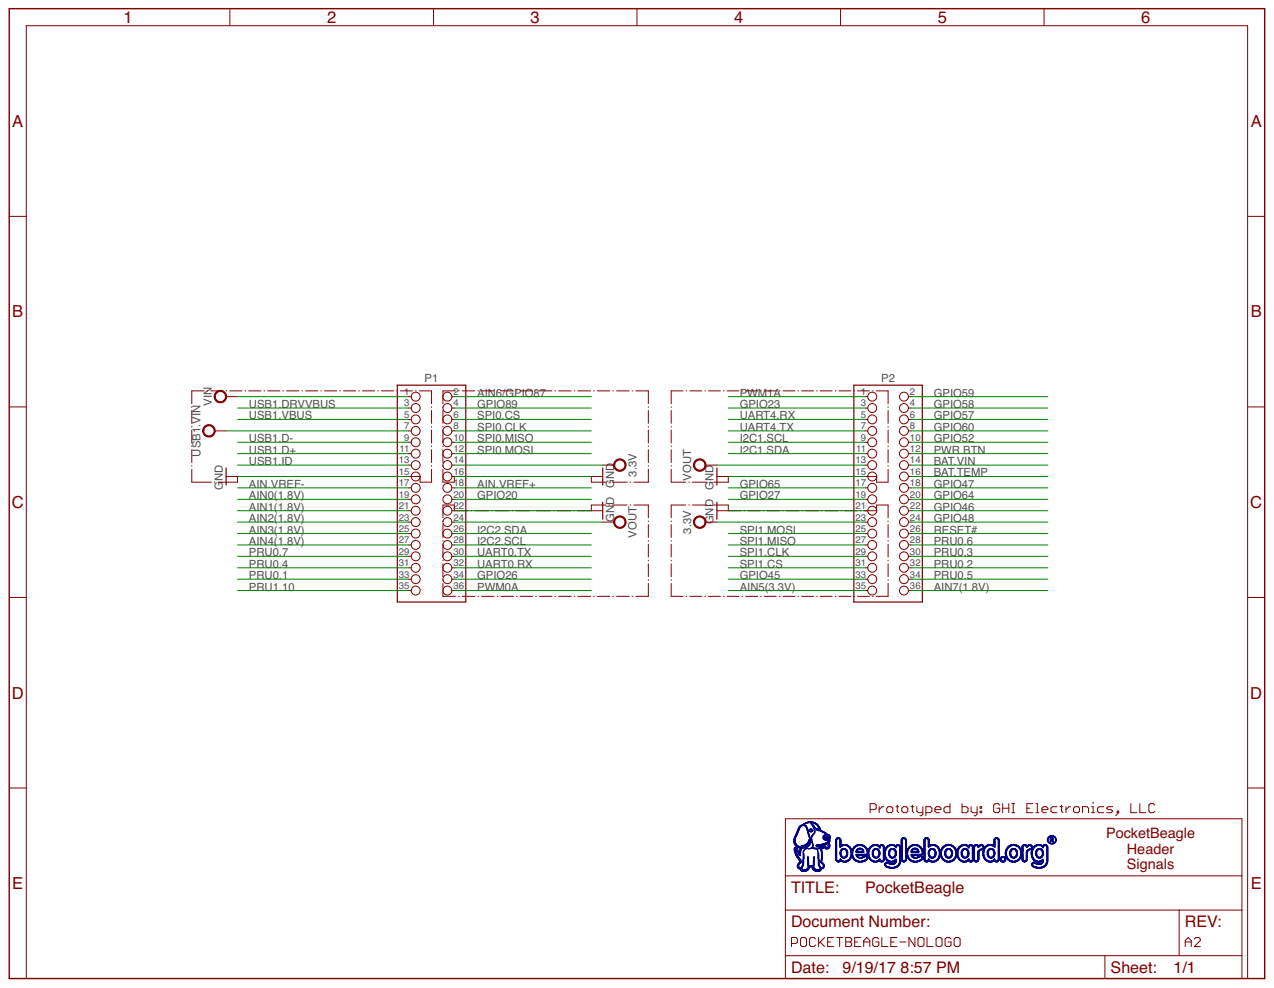
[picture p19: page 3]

GND GND

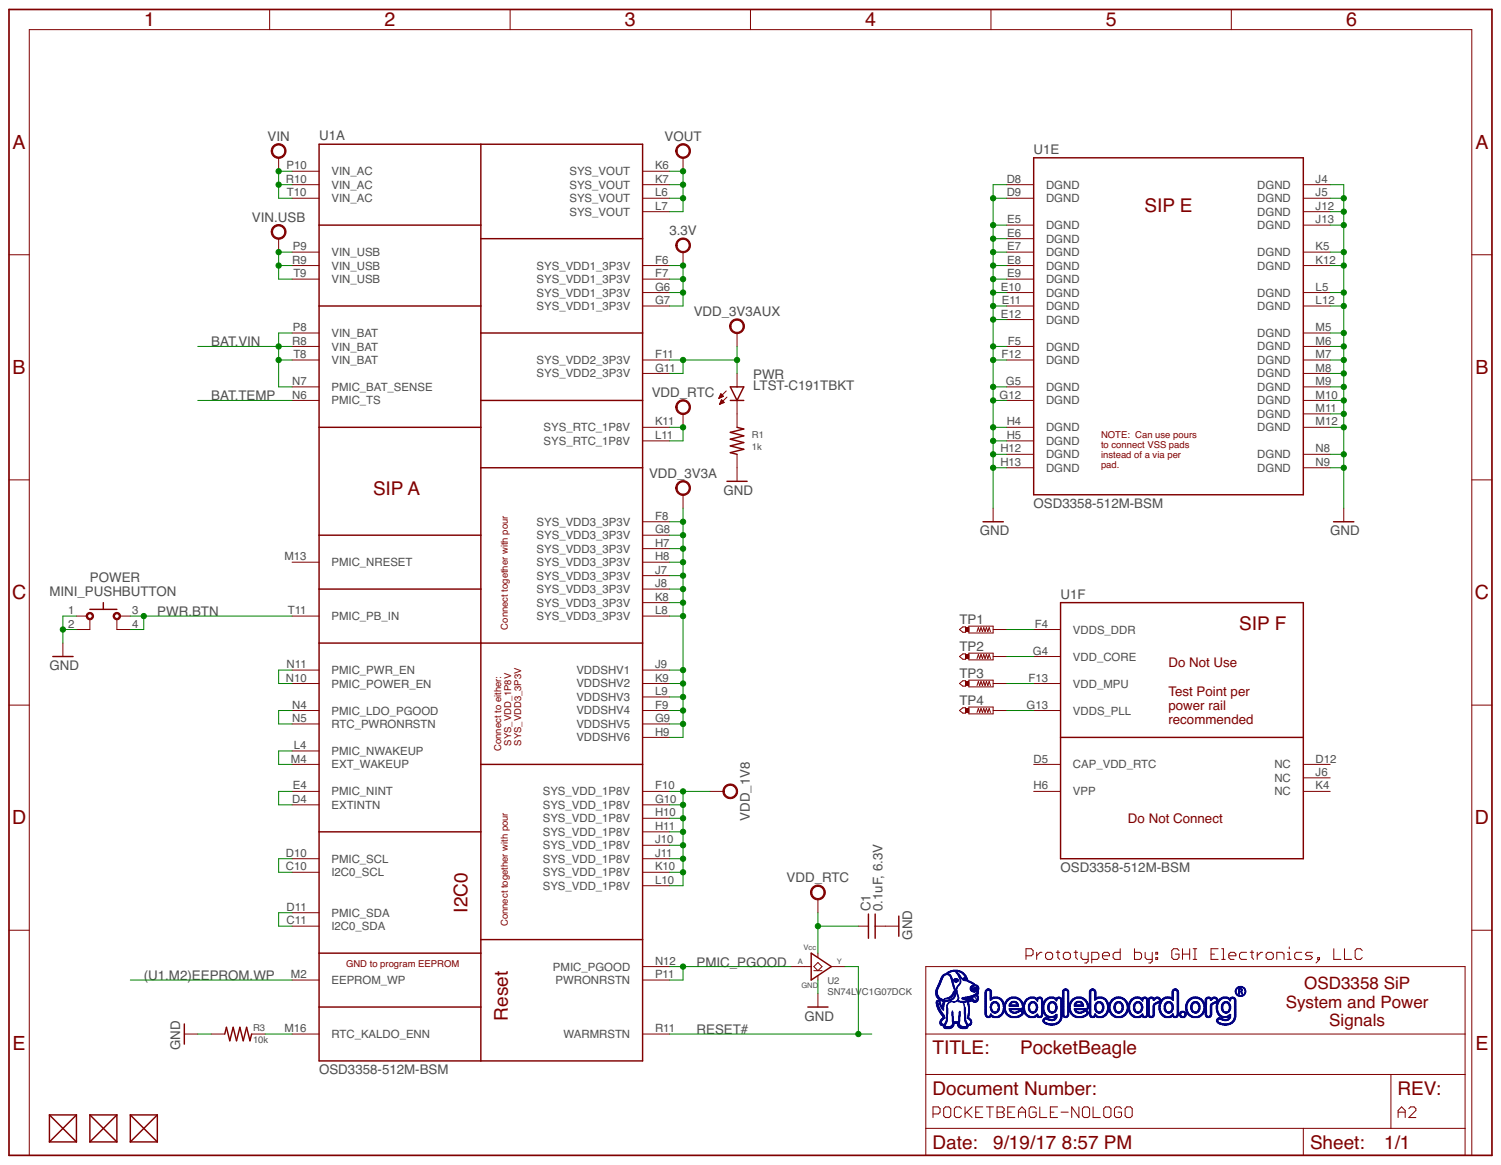
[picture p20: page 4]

NOTE: Can use pours
to connect VSS pads
instead of a via per pad.

SYS_VDD3_3P3V Connect together with pour Connect together with pour

Do Not Use Test Point per power rail recommended

eset Connect to either: SYS_VDD_1P8V

GND to program EEPROM

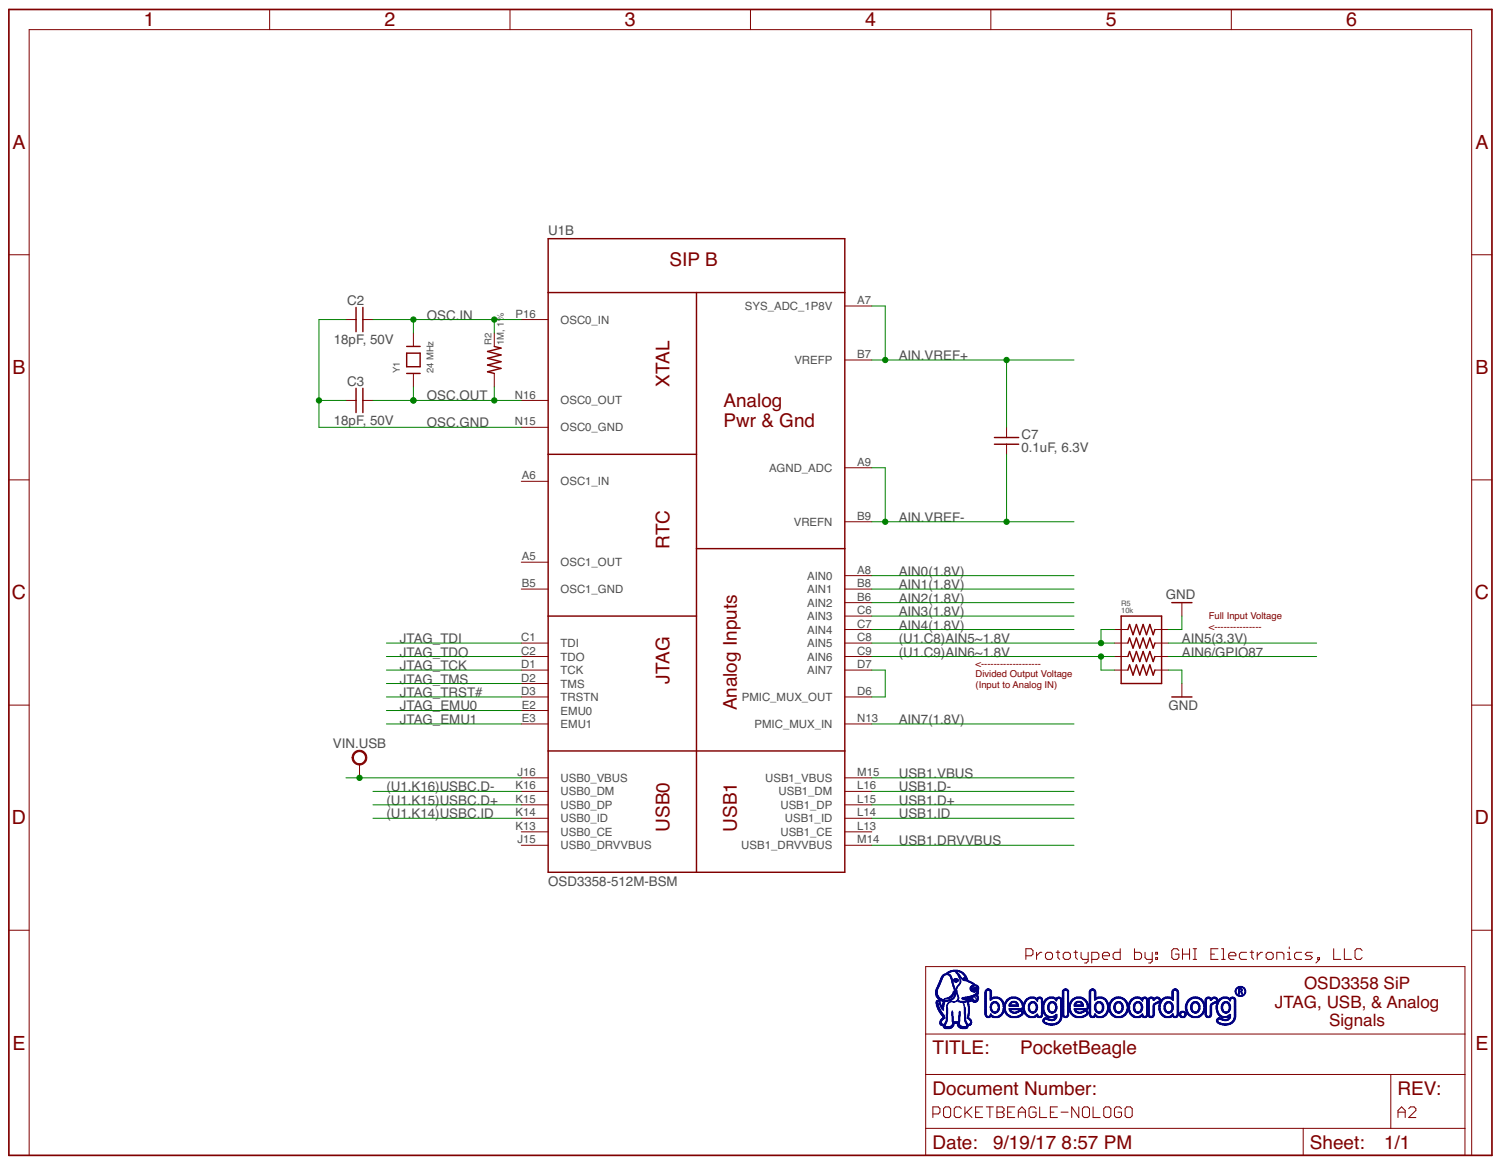
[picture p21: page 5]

Full Input Voltage <--------------- <------------------- Divided Output Voltage

(Input to Analog IN)

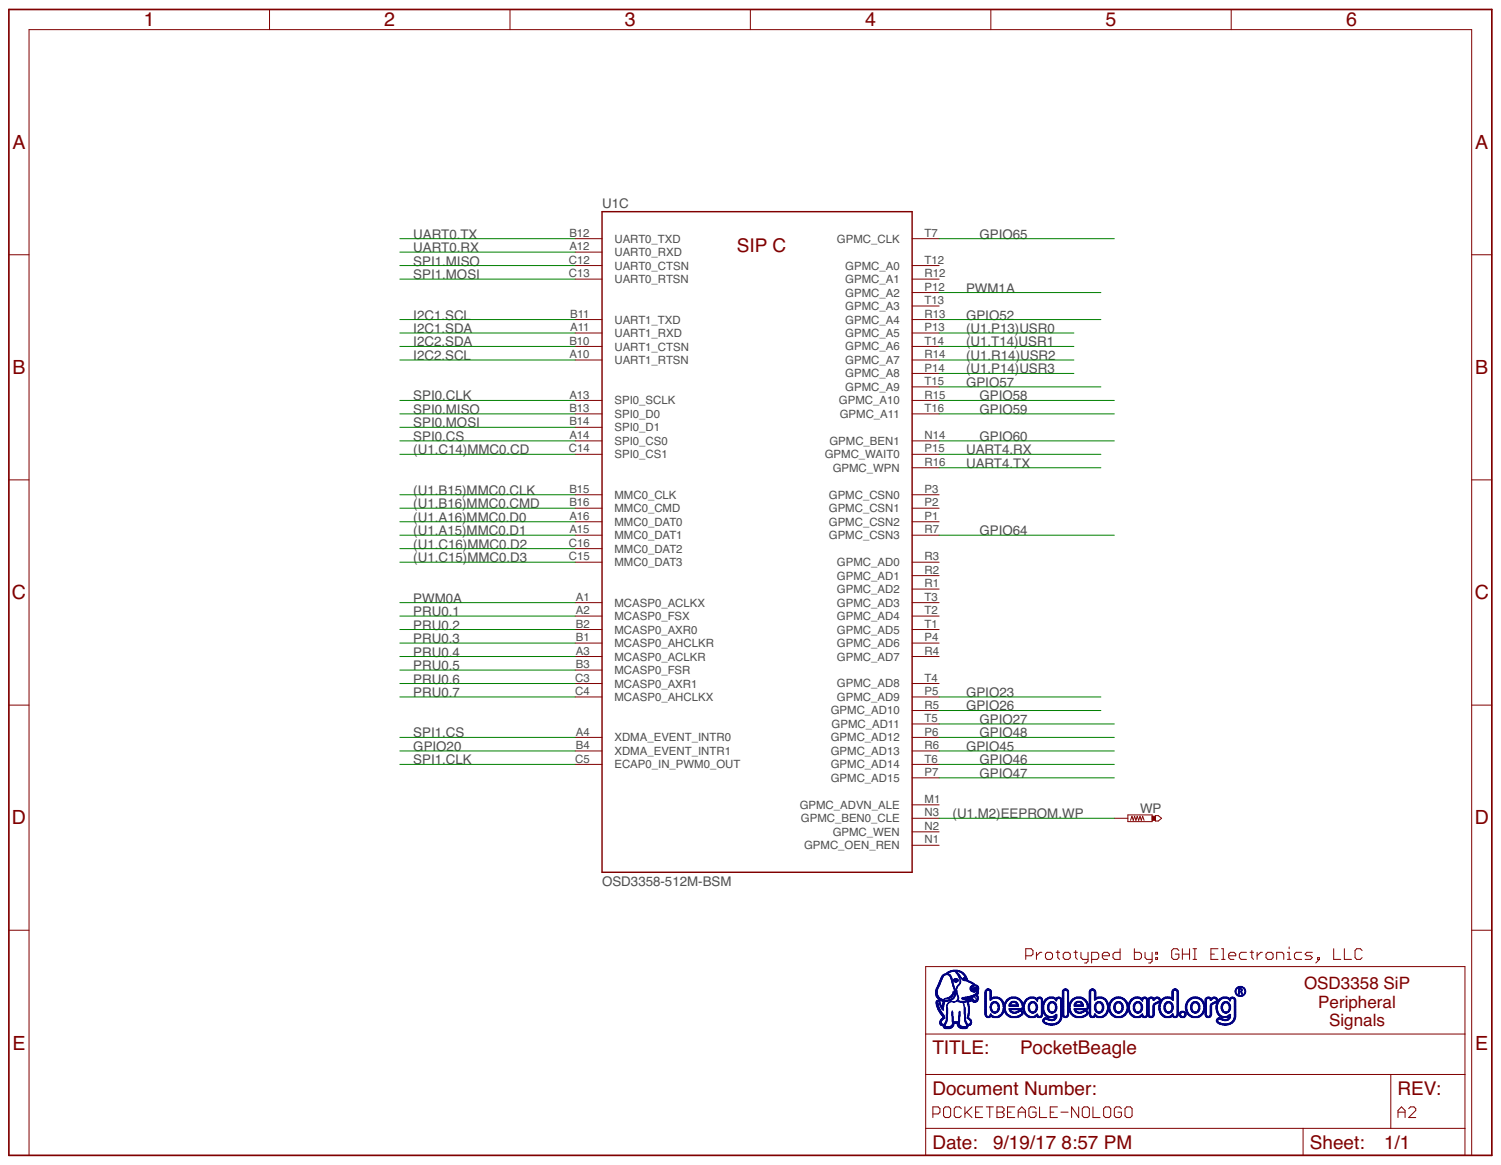
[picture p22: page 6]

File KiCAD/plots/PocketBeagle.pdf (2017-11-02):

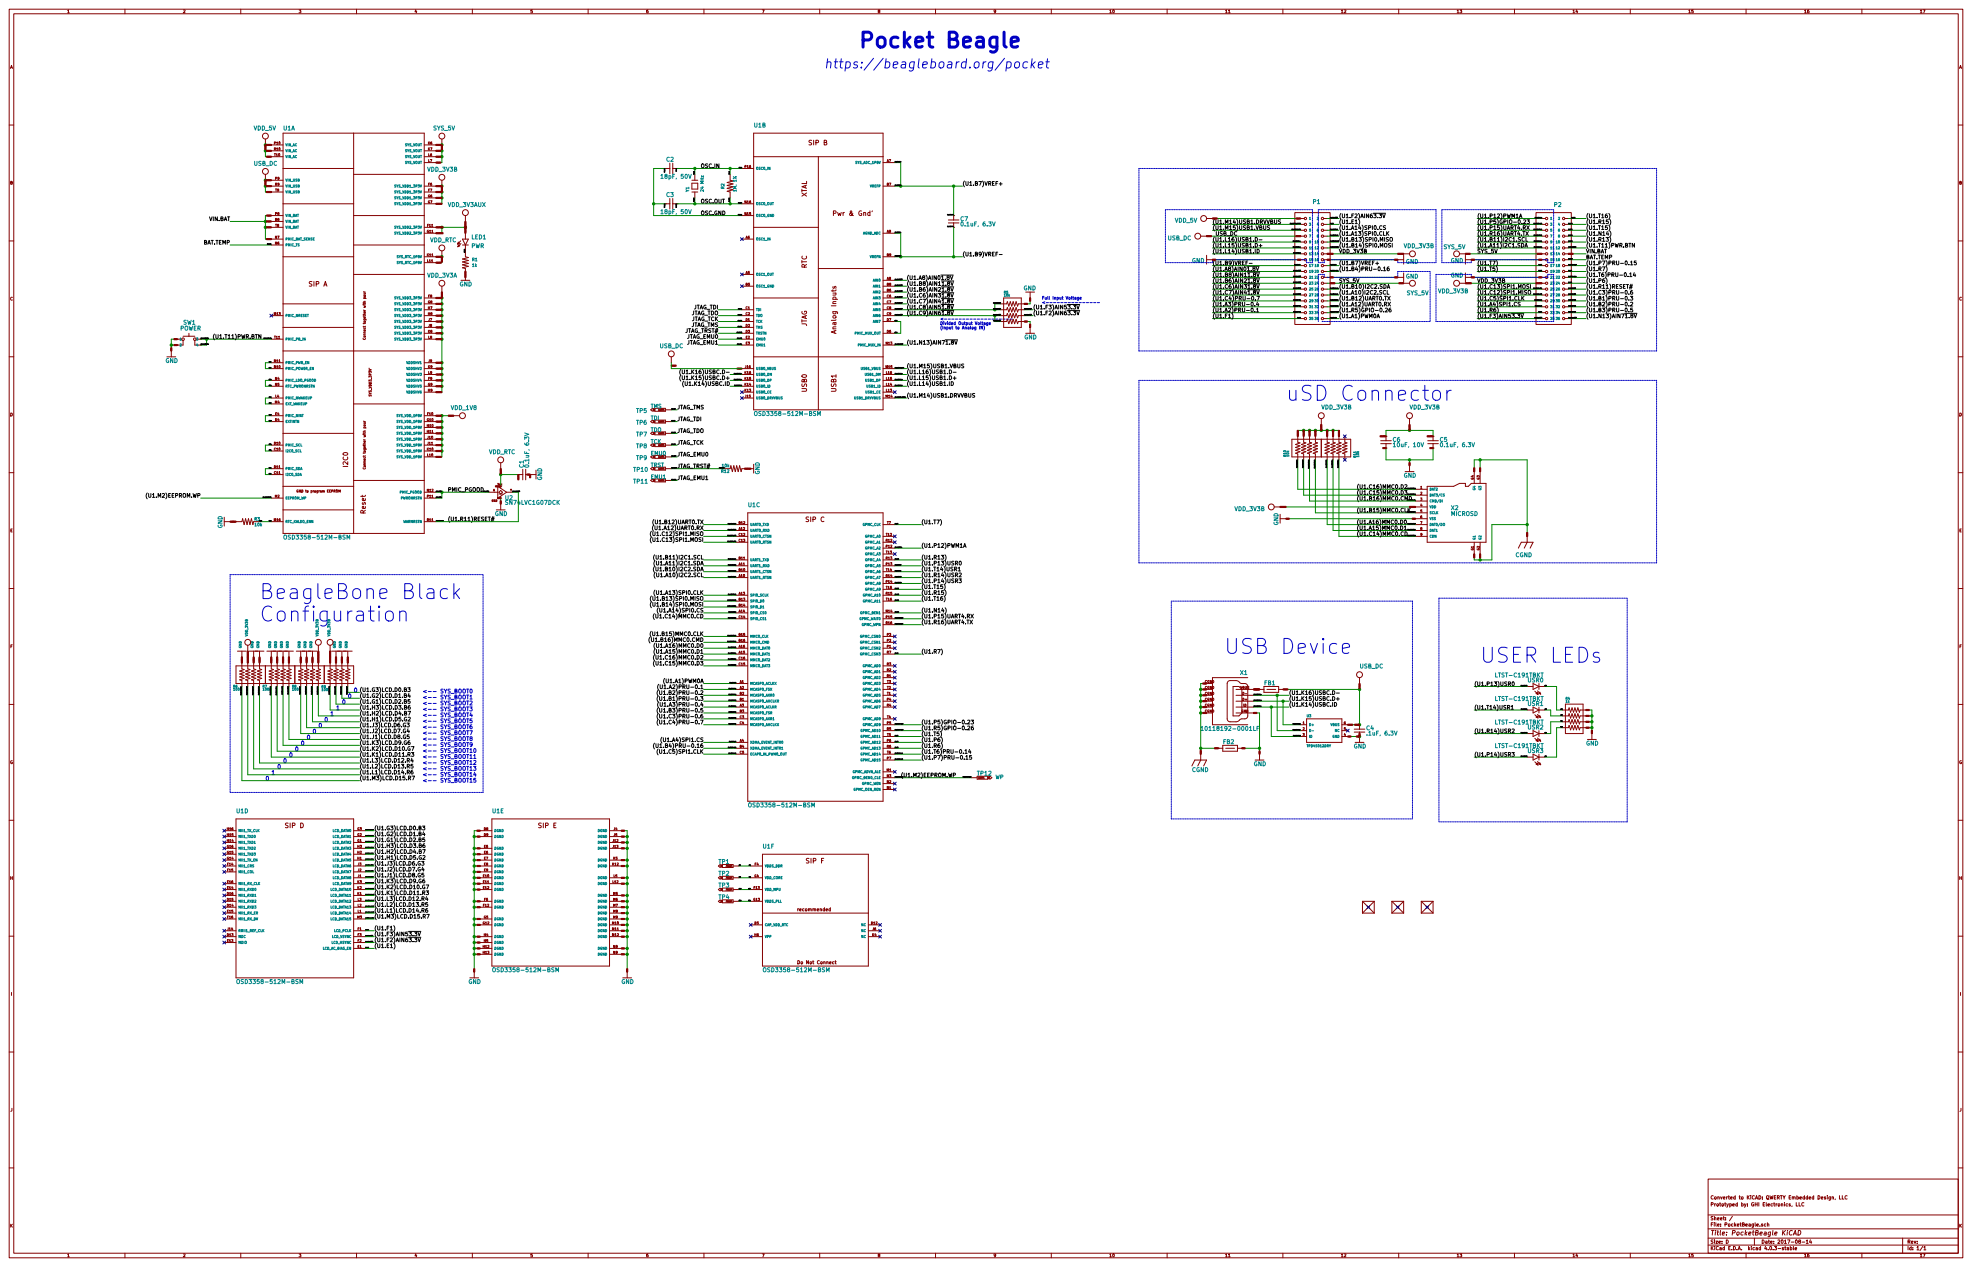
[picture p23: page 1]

https://beagleboard.org/pocket

Full Input Voltage <--------------- <------------------- Divided Output Voltage

(Input to Analog IN) C10.1uF, 6.3V

OSD3358-512M-BSM
Do Not Connect recommended SIP F

Converted to KiCAD: QWERTY Embedded Design, LLC
File: PocketBeagle.sch Sheet: / Prototyped by: GHI Electronics, LLC

Id: 1/1 Title: PocketBeagle KiCAD

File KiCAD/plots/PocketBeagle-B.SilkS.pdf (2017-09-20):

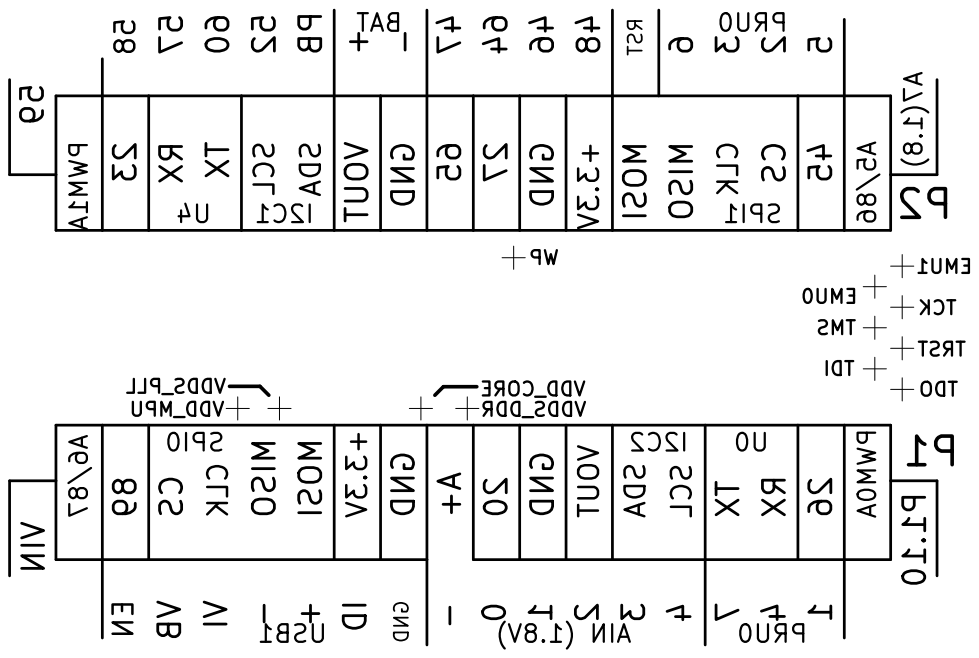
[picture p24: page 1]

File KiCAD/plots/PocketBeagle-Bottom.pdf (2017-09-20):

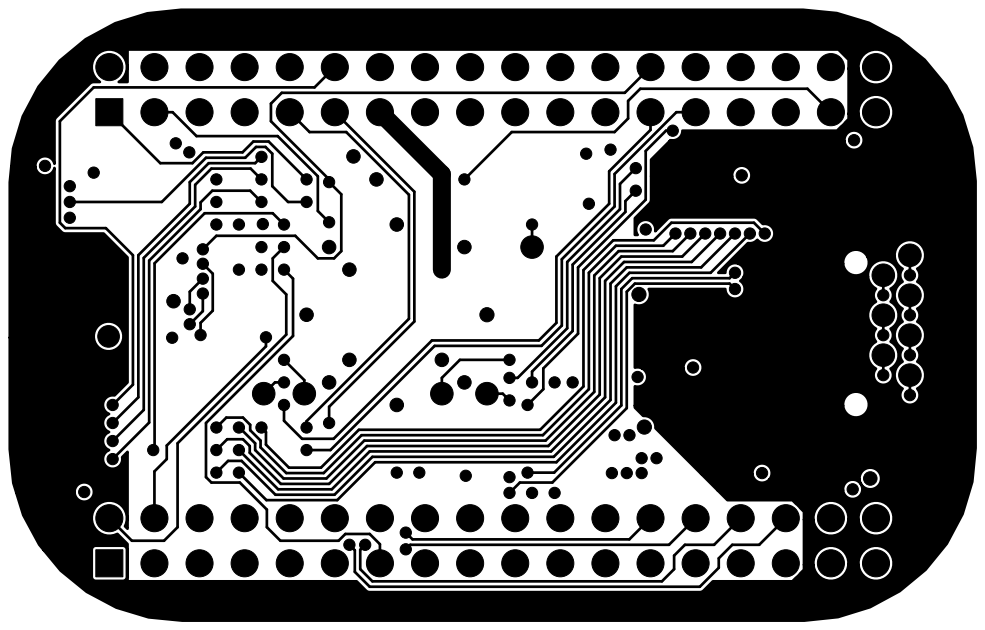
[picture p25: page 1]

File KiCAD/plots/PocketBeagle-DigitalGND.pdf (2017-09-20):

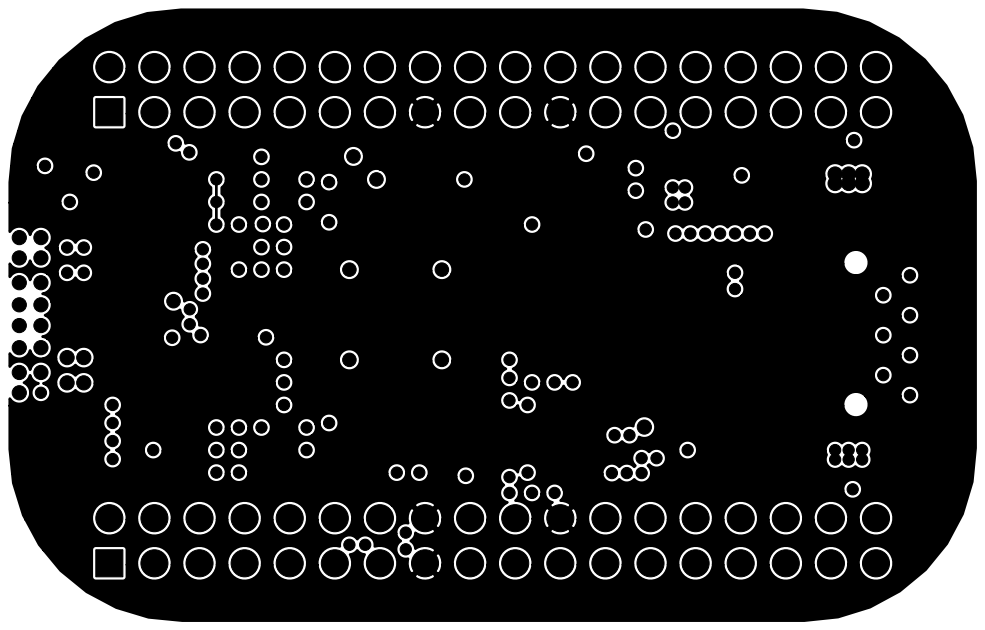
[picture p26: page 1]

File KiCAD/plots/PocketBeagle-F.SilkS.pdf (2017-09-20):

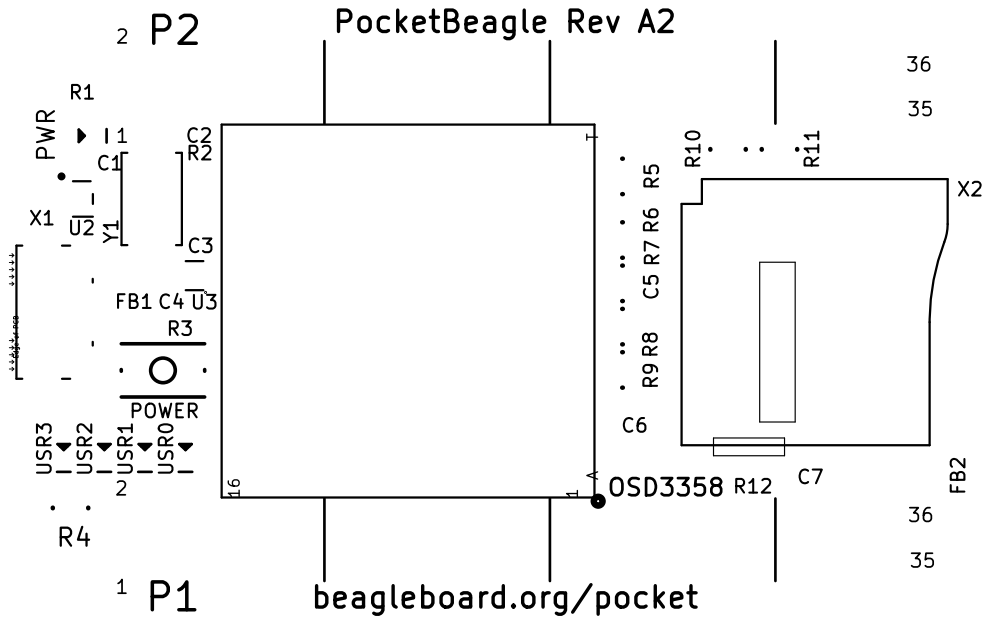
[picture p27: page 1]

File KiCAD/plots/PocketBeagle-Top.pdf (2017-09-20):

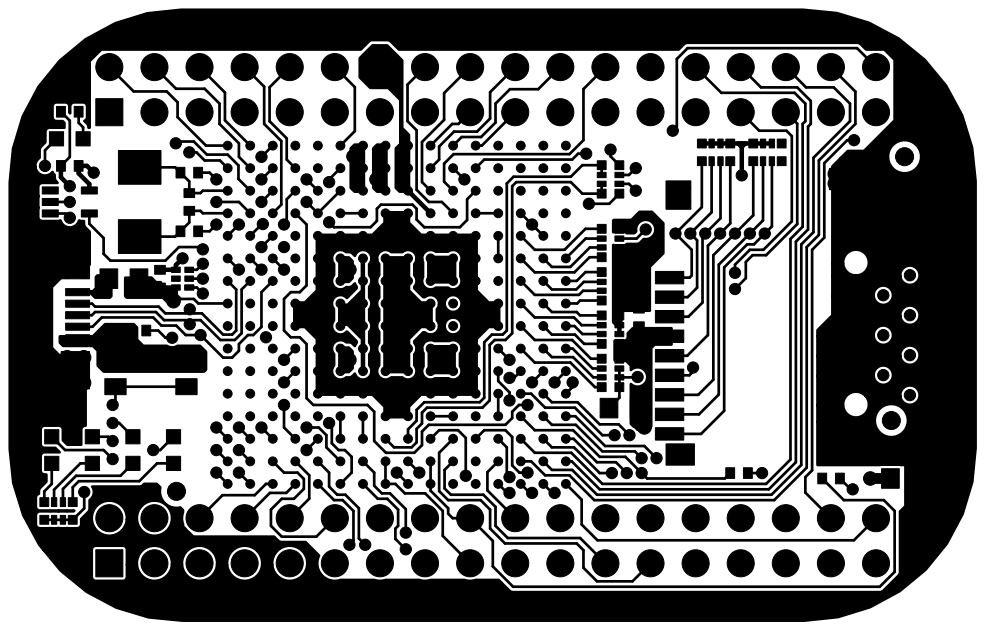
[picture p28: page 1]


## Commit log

2017-08-15 Initial commit of PocketBeagle conversion to KiCAD
    [PocketBeagle.kicad_pcb, PocketBeagle.sch]
2017-08-15 Remove legacy KiCAD library
2017-08-15 Update footprint references for good measure
    [PocketBeagle.kicad_pcb, PocketBeagle.sch]
2017-08-15 Remove paste mask aperture from testpoint
    [PocketBeagle.kicad_pcb, PocketBeagle.sch]
2017-08-15 Pretty up the schematic and OSD component a bit
    [PocketBeagle.kicad_pcb, PocketBeagle.sch]
2017-08-15 Update components again from .pretty libs
    Fixes silkscreen issues.
    [PocketBeagle.kicad_pcb]
2017-08-15 Small tweaks
    [PocketBeagle.kicad_pcb, PocketBeagle.sch]
2017-08-15 Add plots directory for proto release
    [PocketBeagle-B.Paste.gbr, PocketBeagle-B.SilkS.gbr, PocketBeagle-Bottom.gbr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]
2017-09-20 Move KiCAD to a subfolder
    [PocketBeagle-B.Paste.gbr, PocketBeagle-B.SilkS.gbr, PocketBeagle-Bottom.gbr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]
2017-09-20 Initial EAGLE commit
    [PocketBeagle.brd, PocketBeagle.sch]
2017-09-20 Add initial PDF schematic
2017-09-21 Add 3D model.
    [PocketBeagle.step]
2017-09-23 Add a bit more clearance connector->silkscreen.
    If a connector is soldered onto the bottom side of the board, it
    partially covers up the silkscreen. This adds a little more space
    to have that less of a problem.
    [PocketBeagle.kicad_pcb]
2017-09-23 Add Makefile to create gerbers from *.kicad_pcb.
    This also prepares the possibility to add a %%gitversion%%
    string somewhere on the silkscreen which is replaced with the current
    git version (but no such silkscreen is added in this commit).
2017-10-02 Switch the - to T on the silk in the BAT section
    The pin is the battery temperature pin not GND.
    [PocketBeagle.kicad_pcb]
2017-10-02 Fix GPIO silk to read 44 instead of 48
    GPIO44 is incorrectly labelled as GPIO48.
    Still needs to be corrected on the Eagle design.
    [PocketBeagle.kicad_pcb]
2017-10-02 Fix GPIO silk to read 44 instead of 48 on Eagle
    This resolves issue #4.
    [PocketBeagle.brd]
2017-10-02 Update revision to A2a
    [PocketBeagle.brd, PocketBeagle.kicad_pcb]
2017-10-04 Clarify ChipSelect silkscreens.
    o The ChipSelect for SPI0 is CS0, for SPI1 is CS1.
    [PocketBeagle.kicad_pcb]
2017-10-04 Clarify ChipSelect silkscreens on Eagle source.
    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
    [PocketBeagle.brd]
2017-10-11 Sanitized schematic.
    Removed "Pin not connected" errors. Net labels terminate on wire endpoints. Fixed P1 P2 symbol pin number overlap. Added sch heading
    [PocketBeagle.sch]
2017-10-13 Added PDF of updated schematic
2017-11-02 Fix GPIO numbers on pin table
2017-11-07 Update P2_24 signal name
    [PocketBeagle.brd, PocketBeagle.sch]
2017-11-16 Add BOM
    [PocketBeagle_BOM.csv]
2017-12-08 Fix for Fritzing Part
    Schematic View:
    > fixed unconnected connector
    > removed unused paths and connectors
2017-12-12 Fritzing: explode device into editable parts
2017-12-12 Fritzing fixes from el-j
2018-02-01 Add box to BOM
    [PocketBeagle_BOM.csv]
2023-09-18 Add rev A2b files
    [PocketBeagle.sch, PocketBeagle_BOM.csv]
